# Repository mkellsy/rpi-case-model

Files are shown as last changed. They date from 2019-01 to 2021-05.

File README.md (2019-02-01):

# Raspberry Pi 3 B+ Case with Touchscreen


3D source files for the honeycomb Raspberry Pi case and matching touchscreen case.

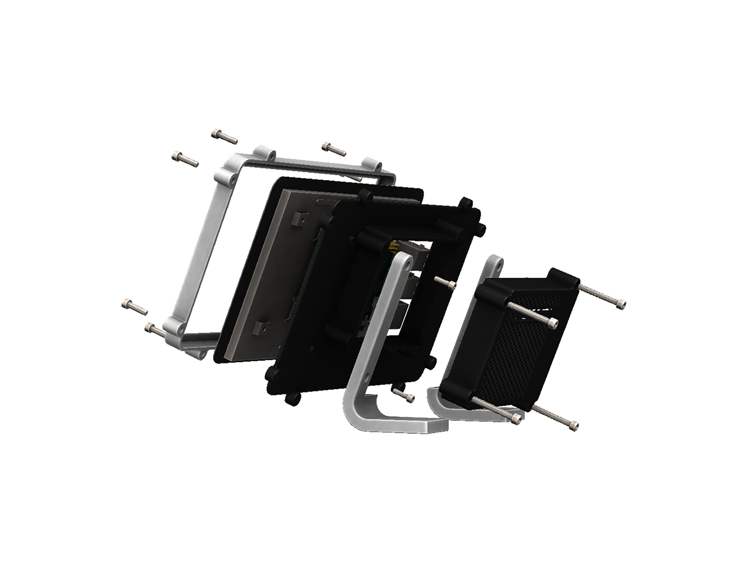
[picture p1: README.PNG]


> This is remixed from 0110-M-P's design on Thingverse, however it is not compatible with it. This has a different bolt pattern.

## Compatibility
- Raspberry Pi 3 Model B+
- Raspberry Pi 3 Model B
- Raspberry Pi 2 Model B
- Raspberry Pi 1 Model B+

## Configurations
This includes multiple mount configurations;
- 75 mm VESA mounts
- 100 mm VESA mounts
- 8020 mounts
- No mounts

Also included are multiple top configurations;
- Standard
- Slotted for display and camera ribbons
- 25 mm and 30 mm fan cutouts
- Clean version (great for modding and remixing)

Special configuration for the official Raspberry Pi touchscreen. Wihch also includes multiple configurations;
- Standard
- Slotted for a camera ribbon
- 25 mm and 30 mm fan cutouts
- Clean version (great for modding and remixing)

## Features
There also is a retainer bracket that can hold the board without using screws inside the case. This bracket does cover the ribbon slots, so it is best used with the default or blank tops. This is not needed fpr the touchscreen because the motherboard attaches to the back of the screen.

## Assembly
To assemble the case you will need;
- 4 x #4-40 x 1/4 socket head cap screws (If you don't use the retainer bracket)
  Used to attach the Raspberry Pi to the base.

- 4 x #6-32 x 3/4 socket head cap screws
  Used to attach the top to the base.

  > The screws will self tap, but it you have a #6-32 tap it is recommended to tab the mount holes on the base.

More detailed instructions can be found here. [Assembly Instructions](https://github.com/mkellsy/rpi-case-model/blob/master/RPI-ASSEMBLY.md).

To assemble the touchscreen case you will need;
- 4 x #4-40 x 3/8 socket head cap screws
  Used to attach the legs and the back to the screen. 

  > The threads on the screen are M3, however #4-40 will work but might alter the threads. I used #4-40 screws because they are easier to find.

- 4 x #6-32 x 1/2 socket head cap screws
  Used to attach the frame to the back.

- 4 x #4-32 x 1 socket head cap screws
  Used to attach the cover to the back.
  
  > The screws will self tap, but it you have a #6-32 tap it is recommended to tab the mount holes on the base.

More detailed instructions can be found here. [Assembly Instructions](https://github.com/mkellsy/rpi-case-model/blob/master/RTS-ASSEMBLY.md).

## Updates

#### 1/21/2019 Update.
- Added slotted, 25 mm fan and 30 mm fan tops without the honeycomb.

#### 1/20/2019 Update.
- Since #4-40 screws are hard to find, I changed the bolt pattern to accommodate #6-32 screws.
- Added support backing for the frame screws.
- Added material behind the frame mounts.
- Added 4 frame mount points to better compress the screen.
- Changed leg geometry to clear the new frame mounts.

#### 1/19/2019 Update.
- Changed the honeycomb pattern, it is much cleaner now.
- Added a retainer that holds the board inside the case without screws.
- Lengthened the touchscreen legs to accommodate larger USB power cables.

#### 1/18/2019 Update.
- Rotated the STL files to lay flat on the print bed. (SolidWorks has a different orientation)
- Added a 8020 mount base.
- Added a slotted top for display and camera ribbons.
- Added a 25 mm and a 30 mm fan top.
- Added a blank top.
- Added a slotted back cover for a camera ribbon.
- Added a 25 mm and a 30 mm fan back cover.
- Added a blank back cover.

#### 1/17/2019 Update.
- Added a no mount base.
- Added a 100 mm VESA mount base.
- Combined the left and right legs into one STL file.
- Increased the thickness of the legs to better fit #4-40 x 3/8 screws without contacting the back of the screen.

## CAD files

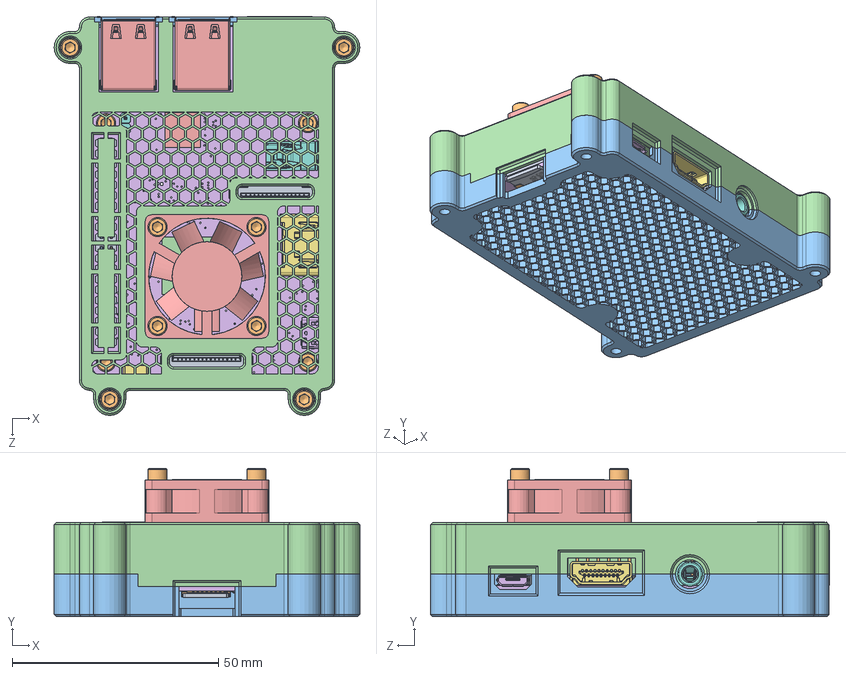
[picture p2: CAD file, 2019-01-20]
RPI-CASE.SLDASM
74.2 x 36.0 x 96.8 mm
Raspberry Pi 3157
Raspberry Pi 3242 x 20
Raspberry Pi 3266 x 20
raspberry_pi_3(bar_180_2x20)
MOLEX_672983090 x 2
molex_0473460001
molex_0471510001
PJ-322
te_1-1734248-5 x 2
MOLEX_1040310811
raspberry_pi_B_(RJ45)
Raspberry Pi 312
Raspberry Pi 314
Raspberry Pi 31
Raspberry Pi 36
Strait Headers
raspberry_pi_B+_(microsd2)
socket head cap screw_ai x 12
RPI-BOTTOM
RPI-TOP-30FAN
30MM-FAN

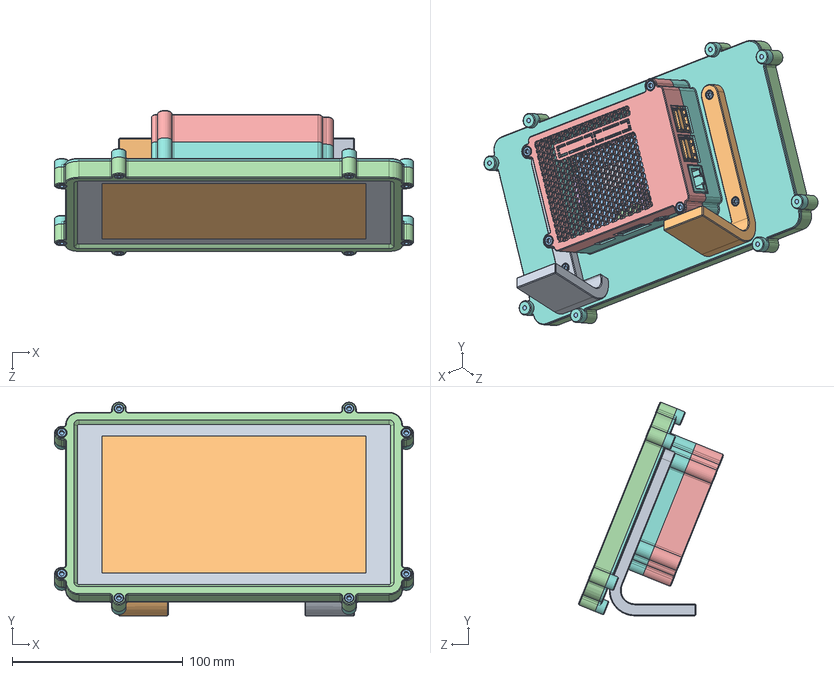
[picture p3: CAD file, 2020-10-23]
RPI3B/TOUCHSCREEN-CASE.SLDASM
210.5 x 125.3 x 85.0 mm
FRAME
FRONT-GLASS
HOUSING
DRIVER-BOARD
RAISER x 4
Raspberry Pi 3157
Raspberry Pi 3242 x 20
Raspberry Pi 3266 x 20
raspberry_pi_3(bar_180_2x20)
MOLEX_672983090 x 2
molex_0473460001
molex_0471510001
PJ-322
te_1-1734248-5 x 2
MOLEX_1040310811
raspberry_pi_B_(RJ45)
Raspberry Pi 312
Raspberry Pi 314
Raspberry Pi 31
Raspberry Pi 36
Strait Headers
raspberry_pi_B+_(microsd2)
pan cross head_am x 4
RTS-BACK
RTS-LEFT-LEG
RTS-RIGHT-LEG
socket head cap screw_ai x 16
RTS-FRAME
RTS-COVER

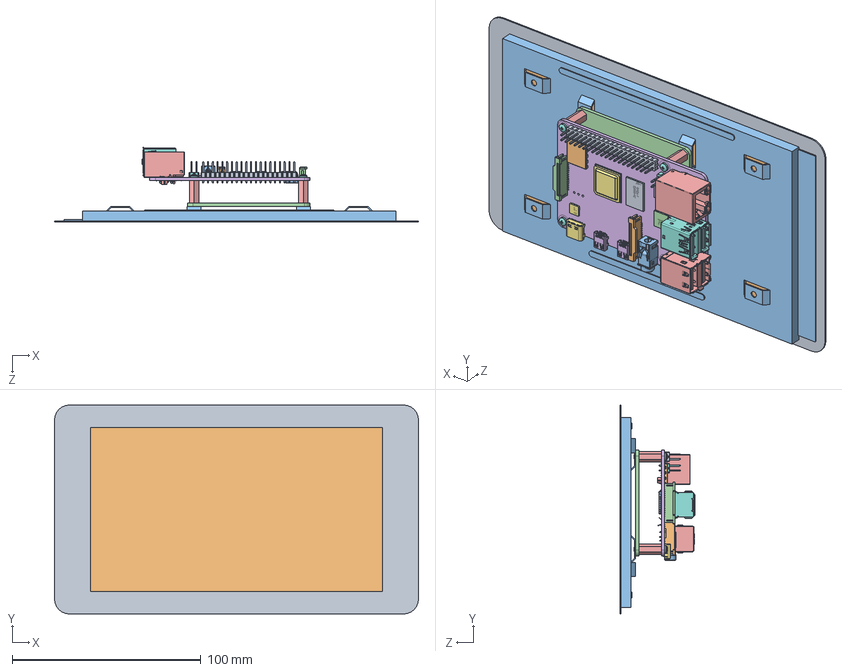
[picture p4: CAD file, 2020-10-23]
RPI4B/TOUCHSCREEN.SLDASM
193.0 x 110.8 x 40.0 mm
FRAME
FRONT-GLASS
HOUSING
DRIVER-BOARD
RAISER x 4
PCB, RPi4ModelB
Broadcom BCM2711B0 CPU, RPi4ModelB
2.54 mm DUPONT MALE PIN HEADER, POE, 2X2, RPi4ModelB
2.54 mm DUPONT MALE PIN HEADER, IO, 2X20, RPi4ModelB
Camera Connector, RPi4ModelB
Microphone Plug, RPi4ModelB
Display Connector, RPi4ModelB
Gigabit Ethernet Port, RPi4ModelB
Female Micro HDMI Connector, RPi4ModelB x 2
Female USB Type C Connector, RPi4ModelB
2X USB3.0 PORTS, RPi4ModelB
91D77 D9WHV 778K, 4 GB LPDDR4 SDRAM, RPi4ModelB
Cypress CYW43455 Wireless Module Cover, RPi4ModelB
SD Card Slot, RPi4ModelB
VIA VL805 PCIe USB 3.0 controller, RPi4ModelB
2X USB2.0 PORTS, RPi4ModelB
Broadcom BCM54213PE Gigabit Ethernet Transceiver, RPi4ModelB
MxL7704 Universal PMIC, RPi4ModelB
pan cross head_am x 4

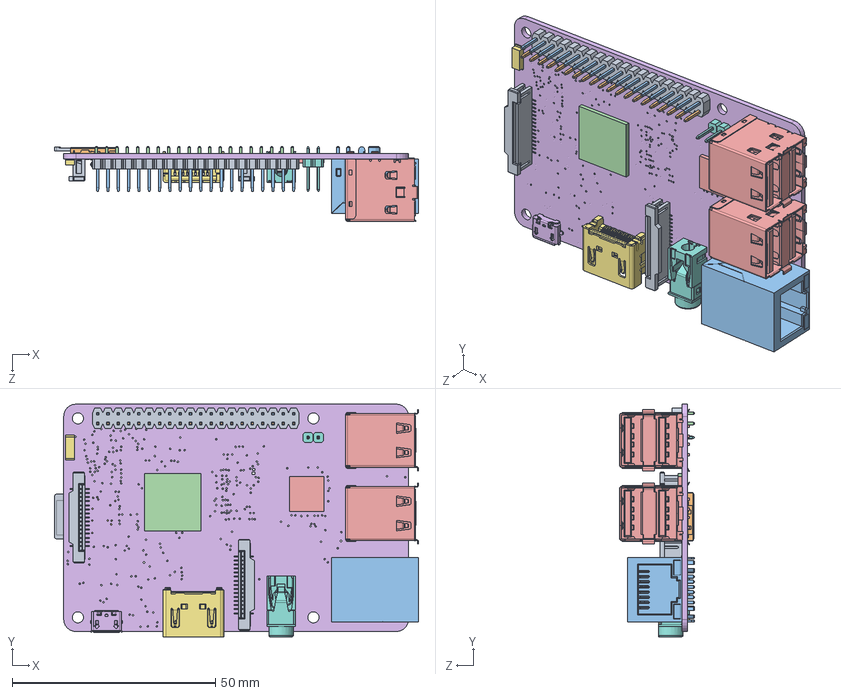
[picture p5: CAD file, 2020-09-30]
RPI3B/BOARD.SLDASM
89.6 x 57.3 x 18.6 mm
Raspberry Pi 3157
Raspberry Pi 3242 x 20
Raspberry Pi 3266 x 20
raspberry_pi_3(bar_180_2x20)
MOLEX_672983090 x 2
molex_0473460001
molex_0471510001
PJ-322
te_1-1734248-5 x 2
MOLEX_1040310811
raspberry_pi_B_(RJ45)
Raspberry Pi 312
Raspberry Pi 314
Raspberry Pi 31
Raspberry Pi 36
Strait Headers
raspberry_pi_B+_(microsd2)

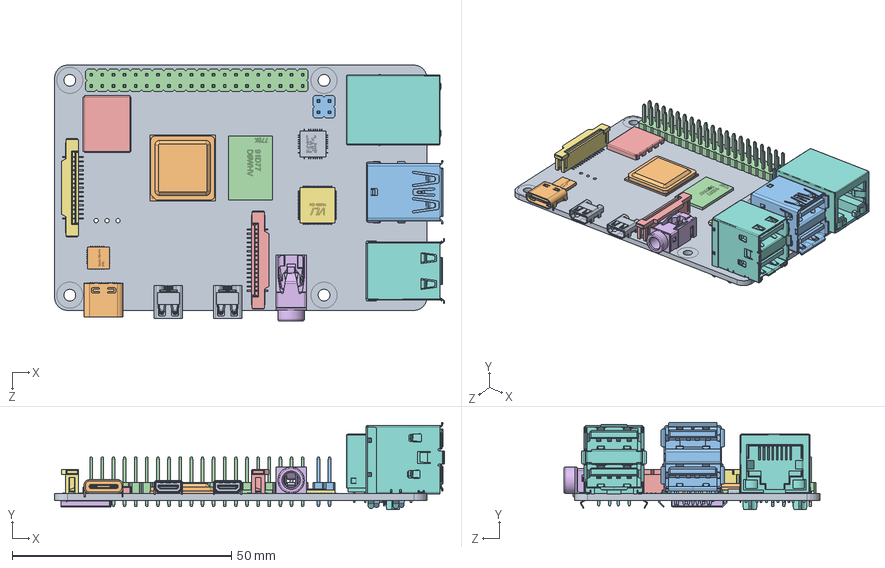
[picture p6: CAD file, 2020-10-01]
RPI4B/BOARD.SLDASM
89.0 x 19.9 x 58.4 mm
PCB, RPi4ModelB
Broadcom BCM2711B0 CPU, RPi4ModelB
2.54 mm DUPONT MALE PIN HEADER, POE, 2X2, RPi4ModelB
2.54 mm DUPONT MALE PIN HEADER, IO, 2X20, RPi4ModelB
Camera Connector, RPi4ModelB
Microphone Plug, RPi4ModelB
Display Connector, RPi4ModelB
Gigabit Ethernet Port, RPi4ModelB
Female Micro HDMI Connector, RPi4ModelB x 2
Female USB Type C Connector, RPi4ModelB
2X USB3.0 PORTS, RPi4ModelB
91D77 D9WHV 778K, 4 GB LPDDR4 SDRAM, RPi4ModelB
Cypress CYW43455 Wireless Module Cover, RPi4ModelB
SD Card Slot, RPi4ModelB
VIA VL805 PCIe USB 3.0 controller, RPi4ModelB
2X USB2.0 PORTS, RPi4ModelB
Broadcom BCM54213PE Gigabit Ethernet Transceiver, RPi4ModelB
MxL7704 Universal PMIC, RPi4ModelB

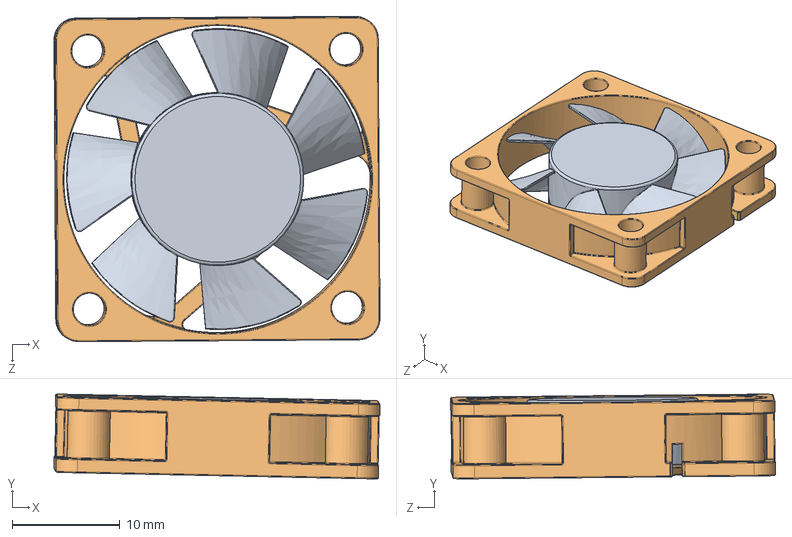
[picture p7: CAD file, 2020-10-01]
RPI4B/COMPONENTS/FAN.SLDASM
30.3 x 7.87 x 30.2 mm
BLADES
HOUSING

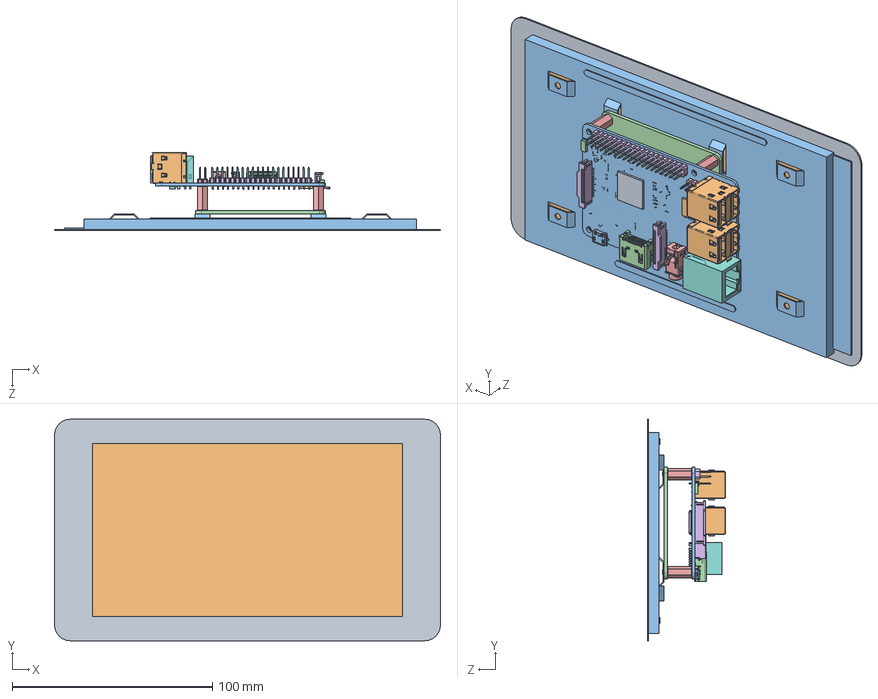
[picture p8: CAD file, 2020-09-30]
RPI3B/TOUCHSCREEN.SLDASM
193.0 x 110.8 x 39.2 mm
FRAME
FRONT-GLASS
HOUSING
DRIVER-BOARD
RAISER x 4
Raspberry Pi 3157
Raspberry Pi 3242 x 20
Raspberry Pi 3266 x 20
raspberry_pi_3(bar_180_2x20)
MOLEX_672983090 x 2
molex_0473460001
molex_0471510001
PJ-322
te_1-1734248-5 x 2
MOLEX_1040310811
raspberry_pi_B_(RJ45)
Raspberry Pi 312
Raspberry Pi 314
Raspberry Pi 31
Raspberry Pi 36
Strait Headers
raspberry_pi_B+_(microsd2)

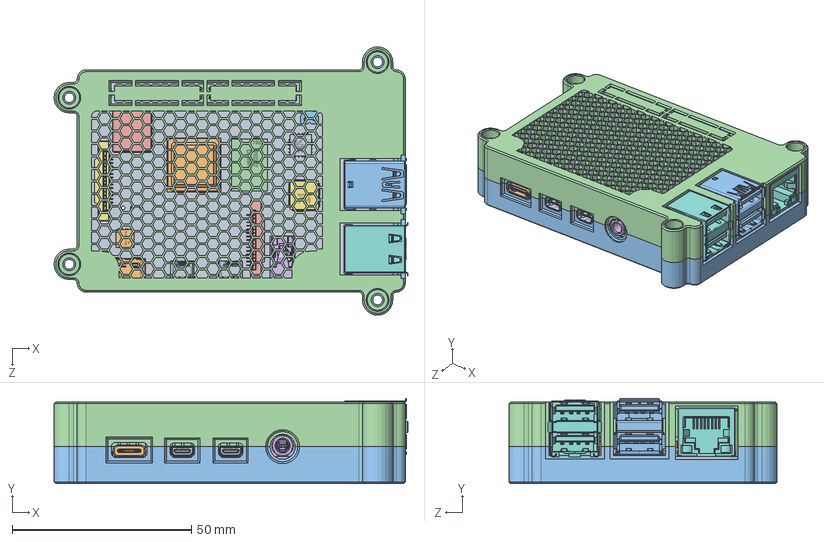
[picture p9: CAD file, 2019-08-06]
RPI4B/CASE.SLDASM
98.8 x 23.8 x 74.9 mm
PCB, RPi4ModelB
Broadcom BCM2711B0 CPU, RPi4ModelB
2.54 mm DUPONT MALE PIN HEADER, POE, 2X2, RPi4ModelB
2.54 mm DUPONT MALE PIN HEADER, IO, 2X20, RPi4ModelB
Camera Connector, RPi4ModelB
Microphone Plug, RPi4ModelB
Display Connector, RPi4ModelB
Gigabit Ethernet Port, RPi4ModelB
Female Micro HDMI Connector, RPi4ModelB x 2
Female USB Type C Connector, RPi4ModelB
2X USB3.0 PORTS, RPi4ModelB
91D77 D9WHV 778K, 4 GB LPDDR4 SDRAM, RPi4ModelB
Cypress CYW43455 Wireless Module Cover, RPi4ModelB
SD Card Slot, RPi4ModelB
VIA VL805 PCIe USB 3.0 controller, RPi4ModelB
2X USB2.0 PORTS, RPi4ModelB
Broadcom BCM54213PE Gigabit Ethernet Transceiver, RPi4ModelB
MxL7704 Universal PMIC, RPi4ModelB
BOTTOM
TOP

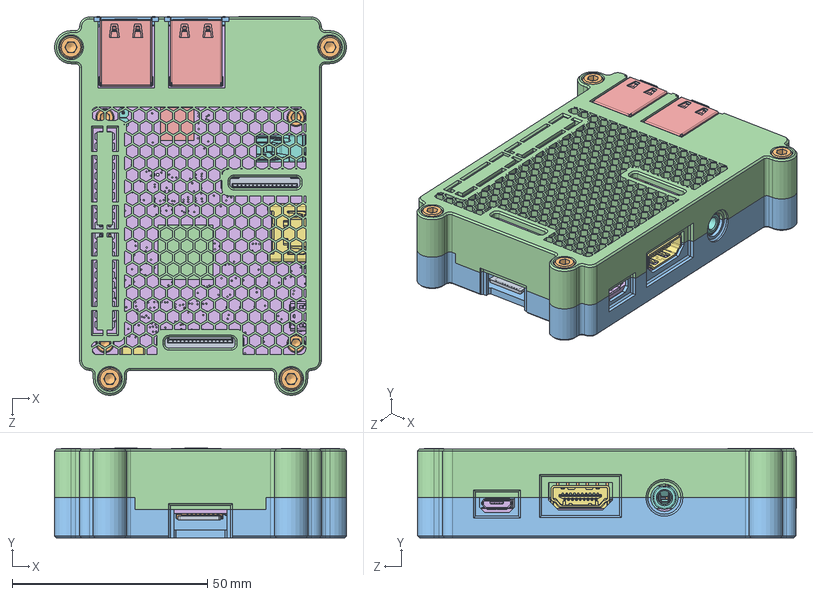
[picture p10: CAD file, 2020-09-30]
RPI3B/CASE.SLDASM
74.9 x 23.0 x 97.2 mm
Raspberry Pi 3157
Raspberry Pi 3242 x 20
Raspberry Pi 3266 x 20
raspberry_pi_3(bar_180_2x20)
MOLEX_672983090 x 2
molex_0473460001
molex_0471510001
PJ-322
te_1-1734248-5 x 2
MOLEX_1040310811
raspberry_pi_B_(RJ45)
Raspberry Pi 312
Raspberry Pi 314
Raspberry Pi 31
Raspberry Pi 36
Strait Headers
raspberry_pi_B+_(microsd2)
socket head cap screw_ai x 8
RPI-BOTTOM
RPI-TOP-SLOTTED

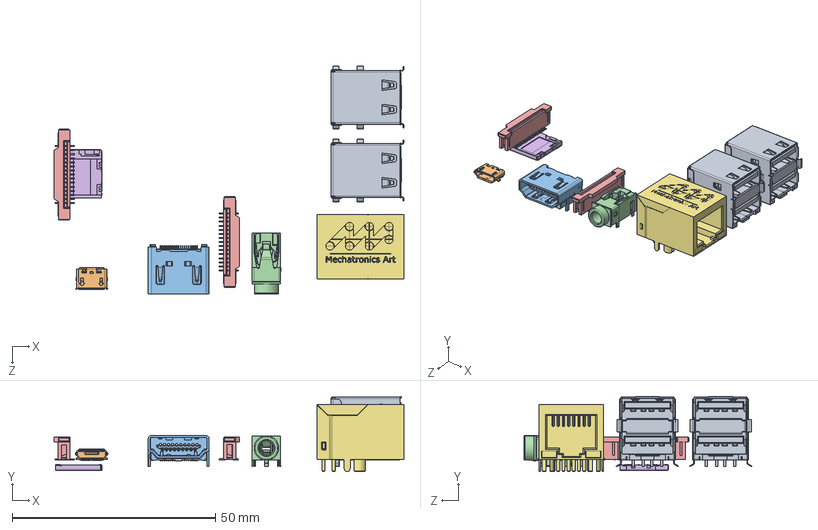
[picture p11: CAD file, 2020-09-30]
RPI3B/BOARD/RPi3_ModelB v1.sldasm
86.1 x 18.5 x 56.1 mm
MOLEX_672983090 x 2
molex_0473460001
molex_0471510001
PJ-322
te_1-1734248-5 x 2
MOLEX_1040310811
raspberry_pi_B_(RJ45)

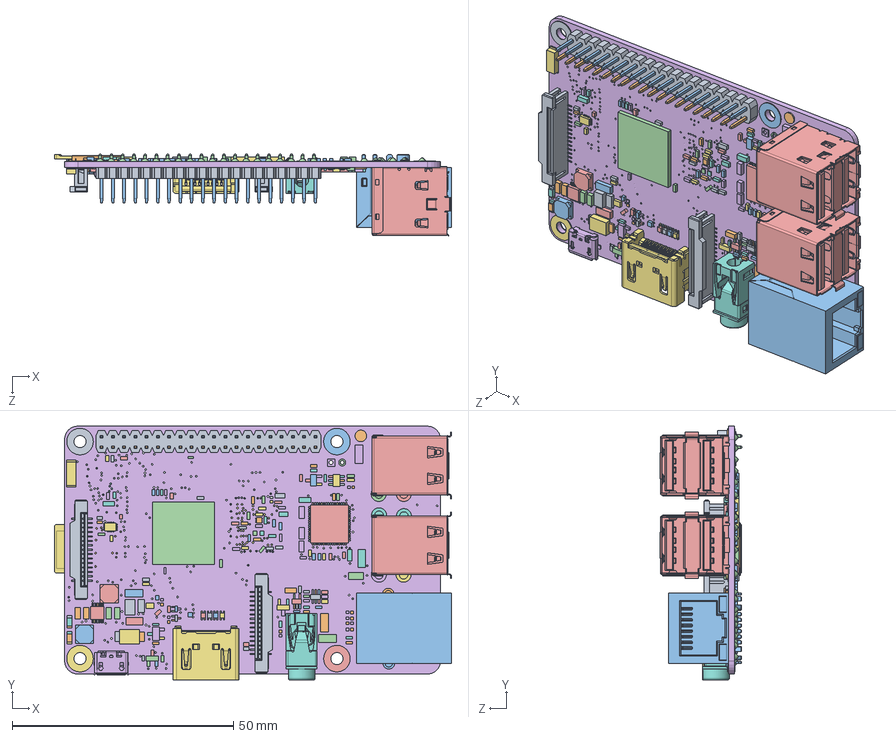
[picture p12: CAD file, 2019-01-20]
RPI3B/BOARD/RPI.SLDASM
89.6 x 57.3 x 18.6 mm
Raspberry Pi 3157
Raspberry Pi 3242 x 20
Raspberry Pi 3266 x 20
raspberry_pi_3(bar_180_2x20)
MOLEX_672983090 x 2
molex_0473460001
molex_0471510001
PJ-322
te_1-1734248-5 x 2
MOLEX_1040310811
raspberry_pi_B_(RJ45)
Raspberry Pi 312
Raspberry Pi 314
Raspberry Pi 3172
Raspberry Pi 3173
Raspberry Pi 3174
Raspberry Pi 3175
Raspberry Pi 3176
Raspberry Pi 3177
Raspberry Pi 3178
Raspberry Pi 3179
Raspberry Pi 3180
Raspberry Pi 3181
Raspberry Pi 3182
Raspberry Pi 3183
Raspberry Pi 3184
Raspberry Pi 3185
Raspberry Pi 3186
Raspberry Pi 3187
Raspberry Pi 3188
Raspberry Pi 3189
Raspberry Pi 3190
Raspberry Pi 3191
Raspberry Pi 3192
Raspberry Pi 3193
Raspberry Pi 3194
Raspberry Pi 3195
Raspberry Pi 3196
Raspberry Pi 3197
Raspberry Pi 3198
Raspberry Pi 3199
Raspberry Pi 3200
Raspberry Pi 3201
Raspberry Pi 3202
Raspberry Pi 3203
Raspberry Pi 3204
Raspberry Pi 3205
Raspberry Pi 3206
Raspberry Pi 3207
Raspberry Pi 3208
Raspberry Pi 3209
Raspberry Pi 3210
Raspberry Pi 3211
Raspberry Pi 3212
Raspberry Pi 3213
Raspberry Pi 3214
Raspberry Pi 3215
Raspberry Pi 3216
Raspberry Pi 3217
Raspberry Pi 3218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

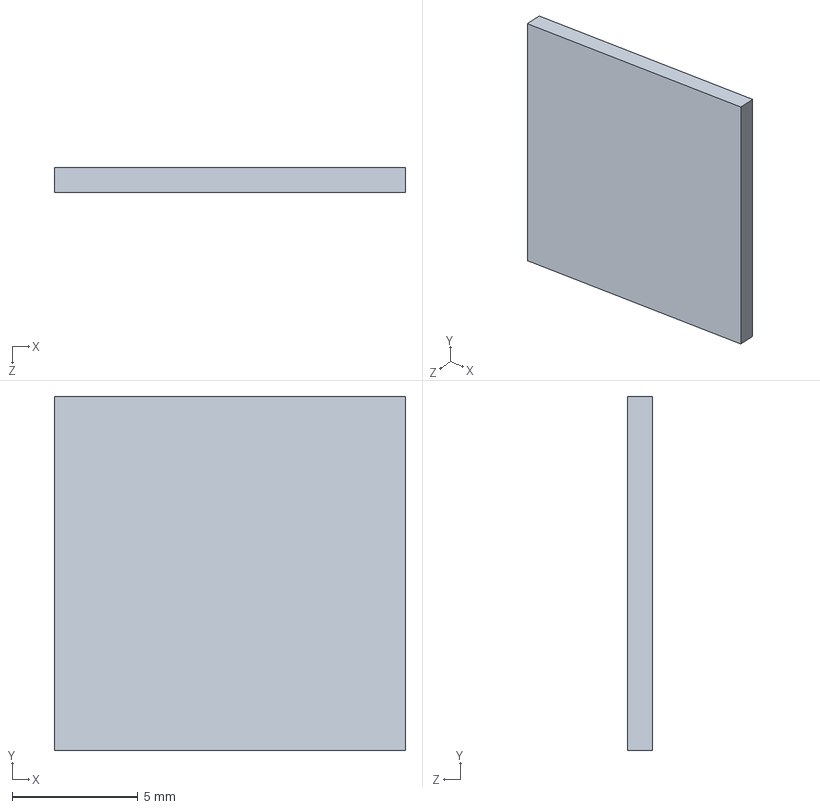
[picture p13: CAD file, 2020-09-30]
RPI3B/BOARD/Raspberry Pi 312.sldprt
14.0 x 14.1 x 1.00 mm

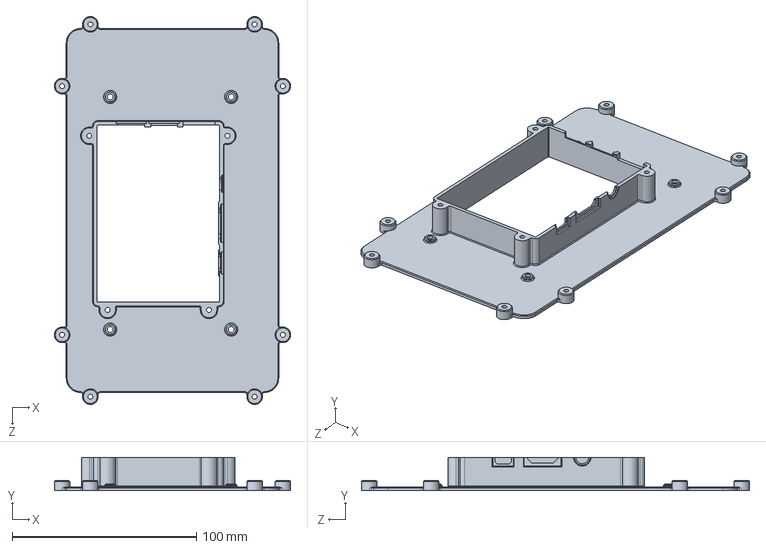
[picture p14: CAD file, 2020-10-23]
RPI3B/CASE/RTS-BACK.SLDPRT
128.3 x 18.1 x 210.5 mm

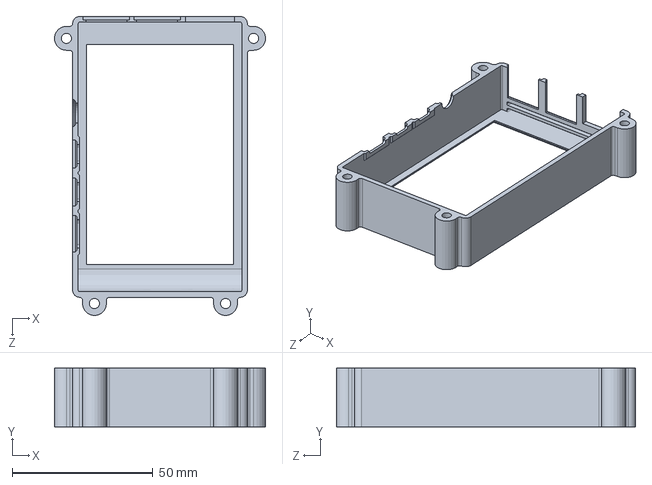
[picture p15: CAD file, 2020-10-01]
RPI4B/BLOWER/TOUCHSCREEN.SLDPRT
74.9 x 20.8 x 106.1 mm

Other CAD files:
RPI3B/PUBLISH/RTS-BACK.STL
RPI4B/BOARD/Gigabit Ethernet Port, RPi4ModelB.SLDPRT
RPI4B/CASE/BEZEL.SLDPRT
RPI4B/COMPONENTS/HOUSING.SLDPRT
RPI3B/BOARD/25MM-FAN.SLDPRT
RPI3B/BOARD/25MM-FAN.STEP
RPI3B/BOARD/30MM-FAN.SLDPRT
RPI3B/BOARD/30MM-FAN.STEP
RPI3B/BOARD/HANRUN2_HR911105A.sldprt
RPI3B/BOARD/MOLEX_1040310811.sldprt
RPI3B/BOARD/MOLEX_672983090.sldprt
RPI3B/BOARD/PJ-322.sldprt
RPI3B/BOARD/Raspberry Pi 31.sldprt
RPI3B/BOARD/Raspberry Pi 310.sldprt
RPI3B/BOARD/Raspberry Pi 3100.sldprt
RPI3B/BOARD/Raspberry Pi 3101.sldprt
RPI3B/BOARD/Raspberry Pi 3102.sldprt
RPI3B/BOARD/Raspberry Pi 3103.sldprt
RPI3B/BOARD/Raspberry Pi 3104.sldprt
RPI3B/BOARD/Raspberry Pi 3105.sldprt
RPI3B/BOARD/Raspberry Pi 3106.sldprt
RPI3B/BOARD/Raspberry Pi 3107.sldprt
RPI3B/BOARD/Raspberry Pi 3108.sldprt
RPI3B/BOARD/Raspberry Pi 3109.sldprt
RPI3B/BOARD/Raspberry Pi 311.sldprt
RPI3B/BOARD/Raspberry Pi 3110.sldprt
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

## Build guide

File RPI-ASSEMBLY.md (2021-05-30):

# Raspberry Pi Case Assembly Instructions
This guide will walk you through assembling the Raspberry Pi case. All of the tools and hardware should be available at Amazon, Home Depot or Ace Hardware.

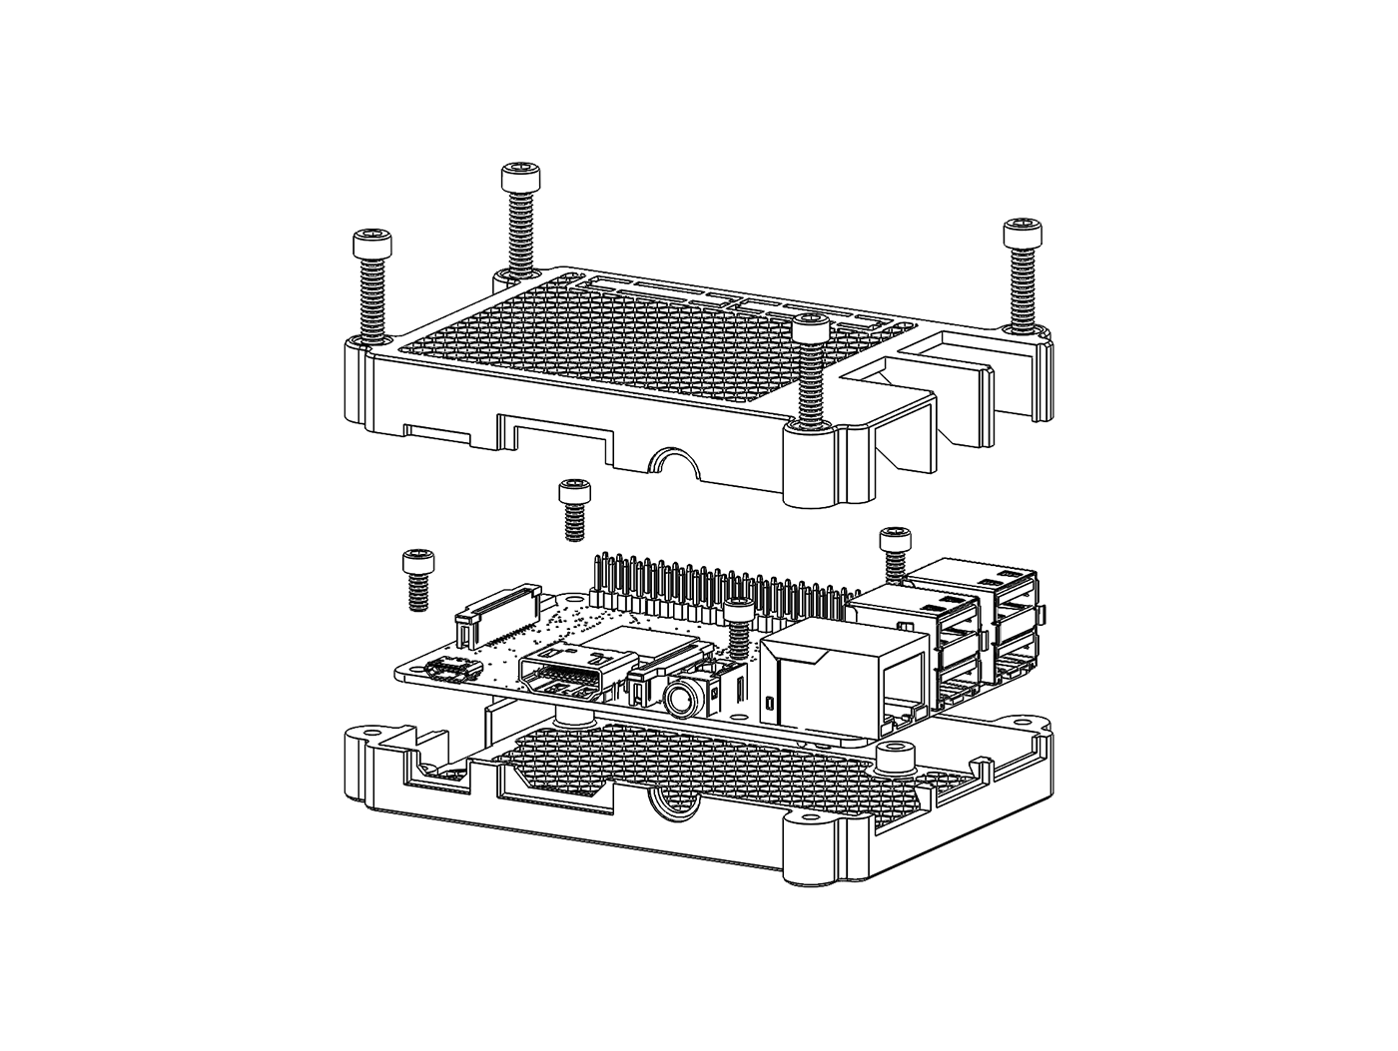
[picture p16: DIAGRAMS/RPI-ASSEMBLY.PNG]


## Required Tools and Hardware
- A #6-32 tap.
- 7/64 and 3/32 hex wrench.
- 4 x #4-40 x 1/4 stainless socket head cap screws. (RPI 3 Version Only)
- 4 x #6-32 x 3/4 stainless socket head cap screws.

> M3 screws will work too. Imperial threads are listed because they are easier to find in the U.S.

## Tapping
First you will need to tap the holes on the RPI-BOTTOM. Tapping is not required as the screws are harder than the plastic. However tapping will create a more consistant thread, as tapping removes material vs. compressing it.

## Assembly
Once you are finished printing the parts, you are now ready to assemble.

### Step 1
Attach the Raspberry Pi to the RPI-BOTTOM.

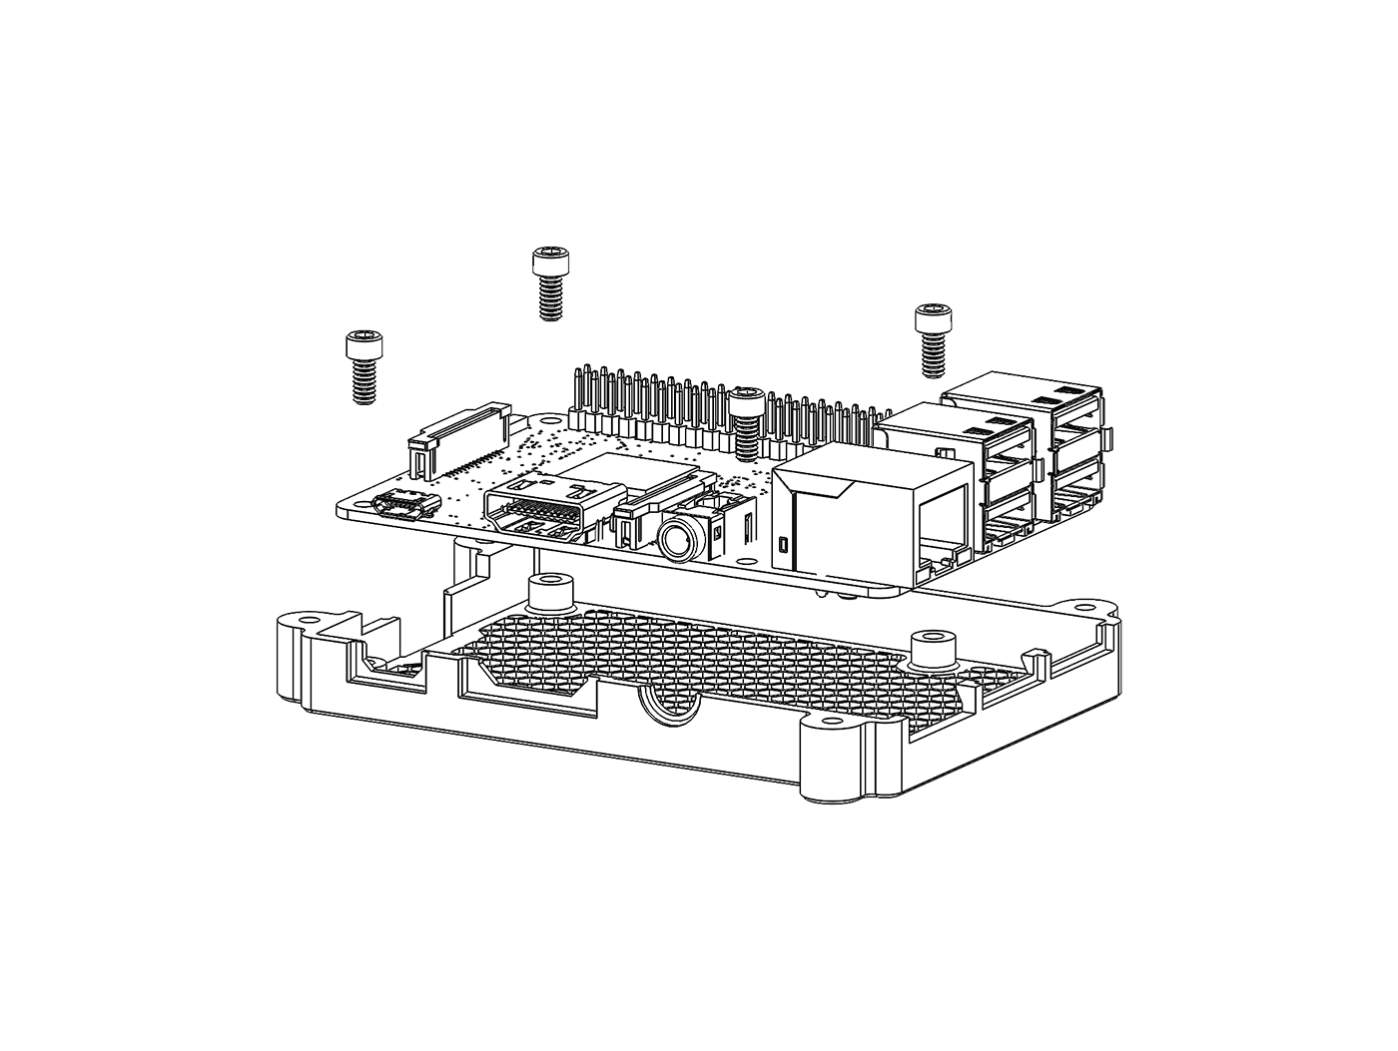
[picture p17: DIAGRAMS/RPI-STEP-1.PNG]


1. Allign the board to the 4 raisers on the RPI-BOTTOM.
2. Attach using 4 #4-40 x 1/4 stainless socket head cap screws. (RPI 3 Version Only)

  > #4-40 taps are hard to find. These screws will need to be self tapped.

### Step 2
Attach the RPI-TOP.

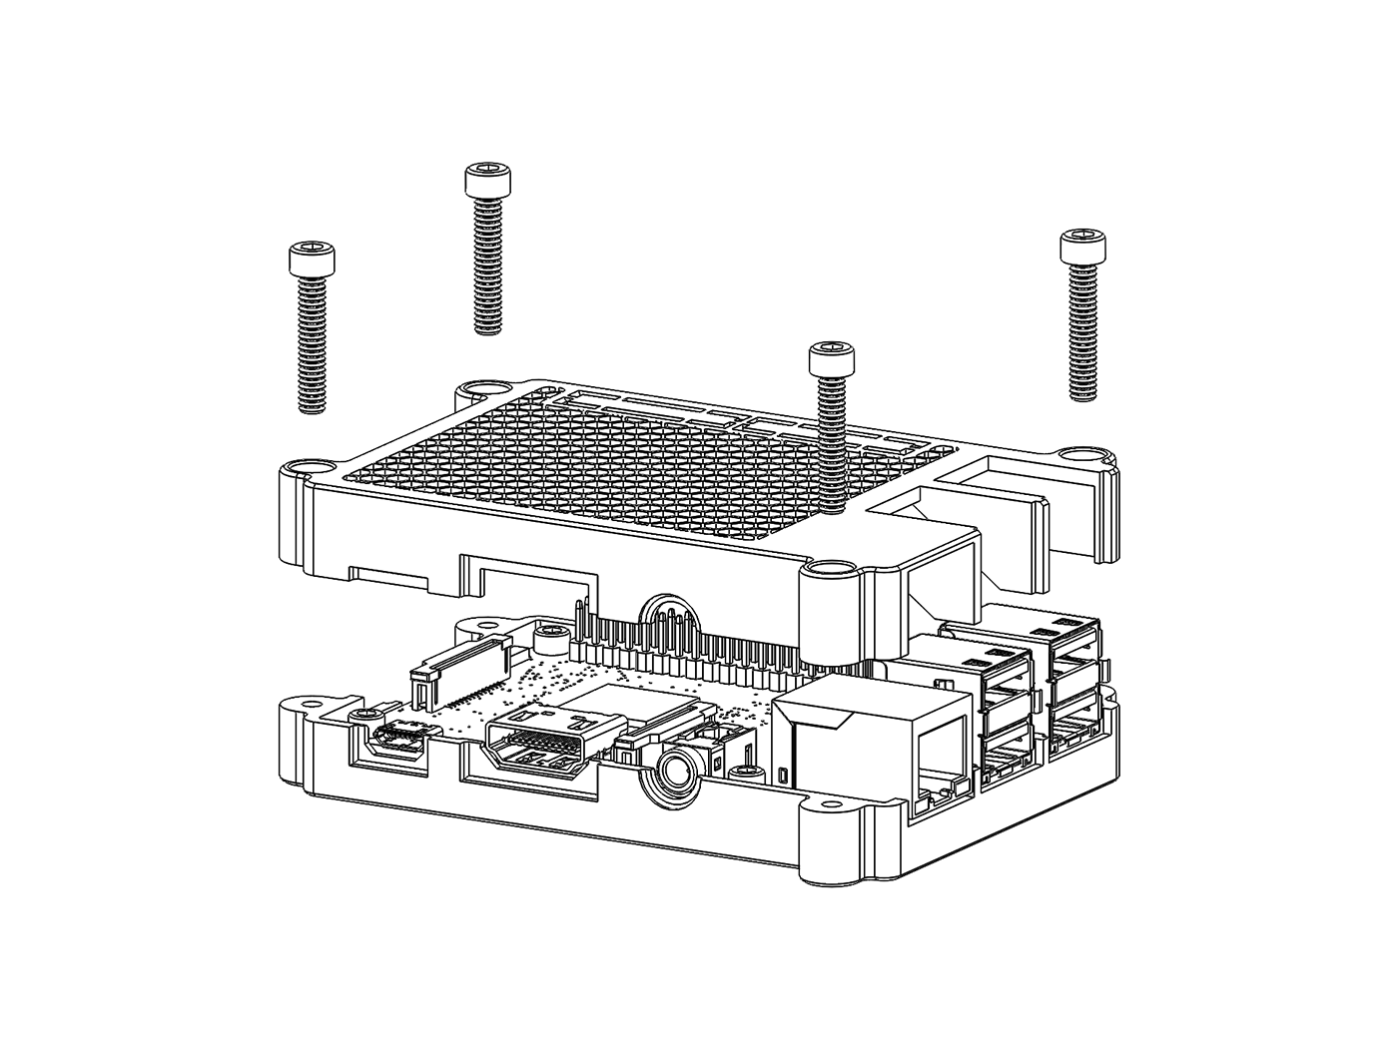
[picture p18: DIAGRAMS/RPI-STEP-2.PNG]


1. Allign the top with the four mount points on the RPI-BOTTOM.
2. Secure the RPI-TOP with 4 #6-32 x 3/4 stainless socket head cap screws.

## Assembly, Screwless Version (RPI 3 Version Only)
If you do not want to secure the Raspberry Pi into the case using screws, you can use the retainer and not use the screws.

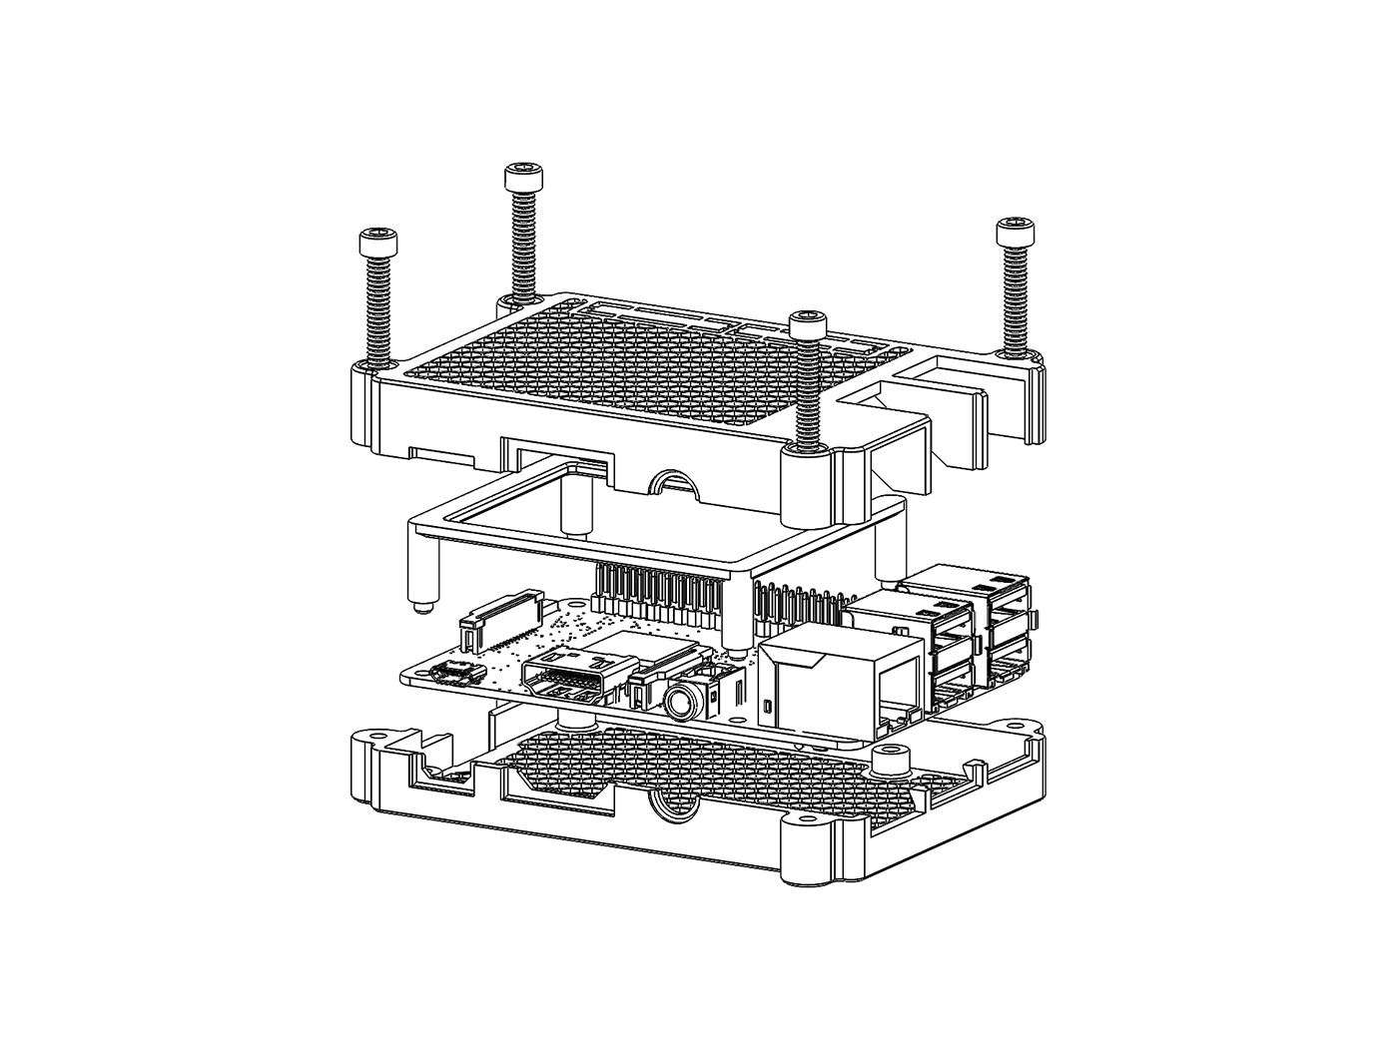
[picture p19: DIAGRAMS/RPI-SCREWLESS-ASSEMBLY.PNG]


> The RPI 4 version has the retainer built into the top.

### Step 1
Position the Raspberry Pi and the RPI-RETAINER in the RPI-BOTTOM.

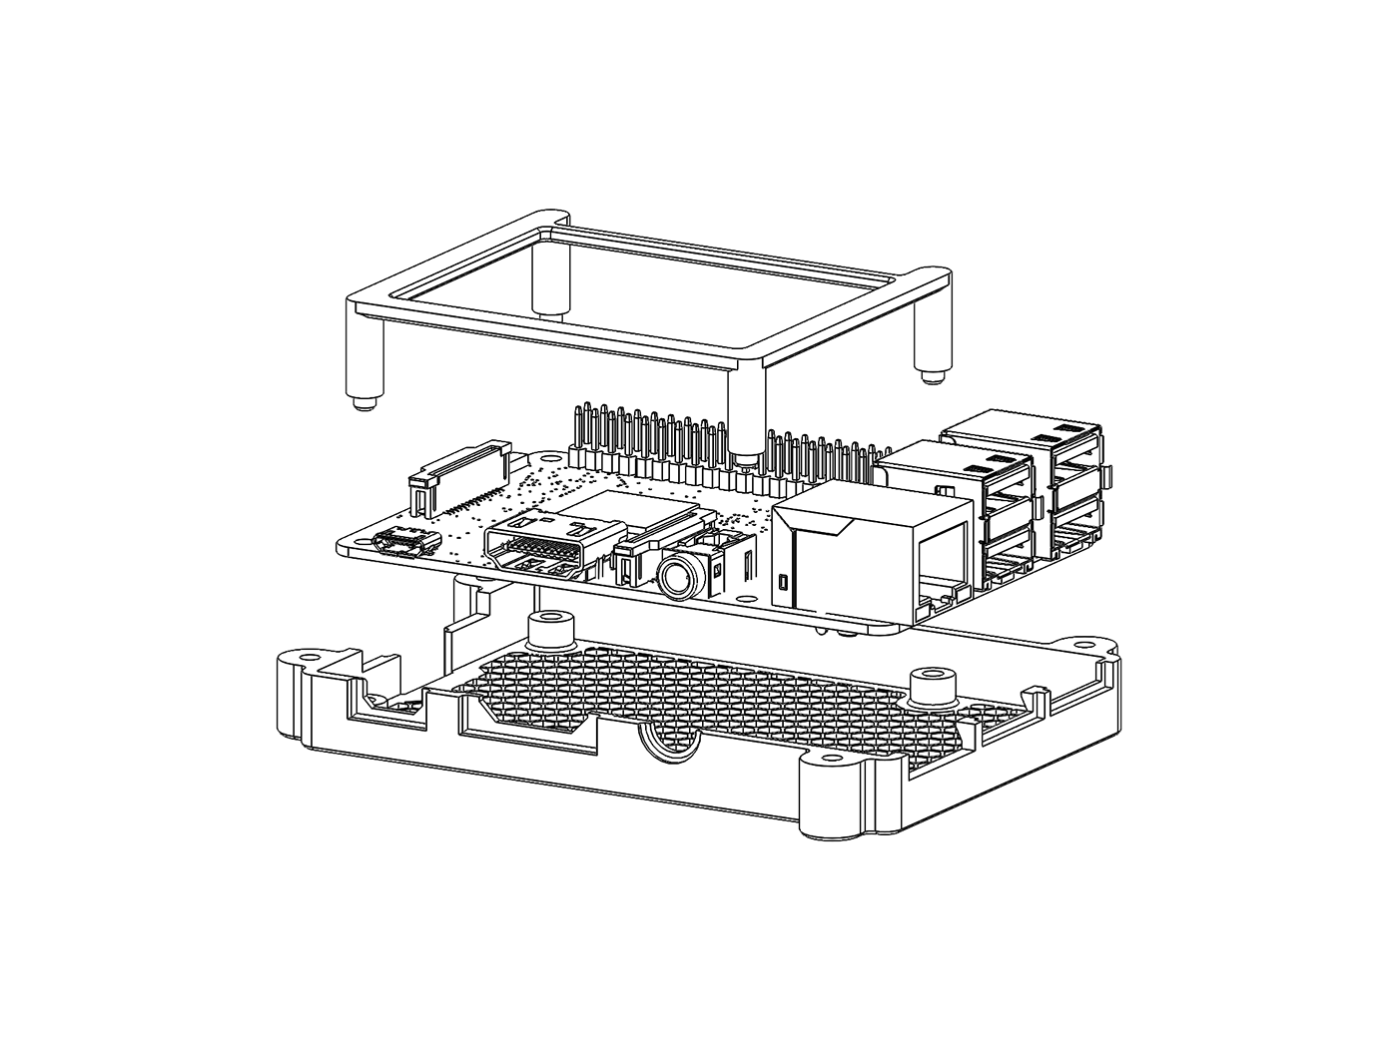
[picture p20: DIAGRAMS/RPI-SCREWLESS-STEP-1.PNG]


1. Allign the board to the 4 raisers on the RPI-BOTTOM.
2. Place the RPI-RETAINER into the 4 raisers on the RPI-BOTTOM through the board.

  > One side of the retainer is offset. This is done to clear the pins on the Raspberry Pi.

### Step 2
Attach the RPI-TOP.

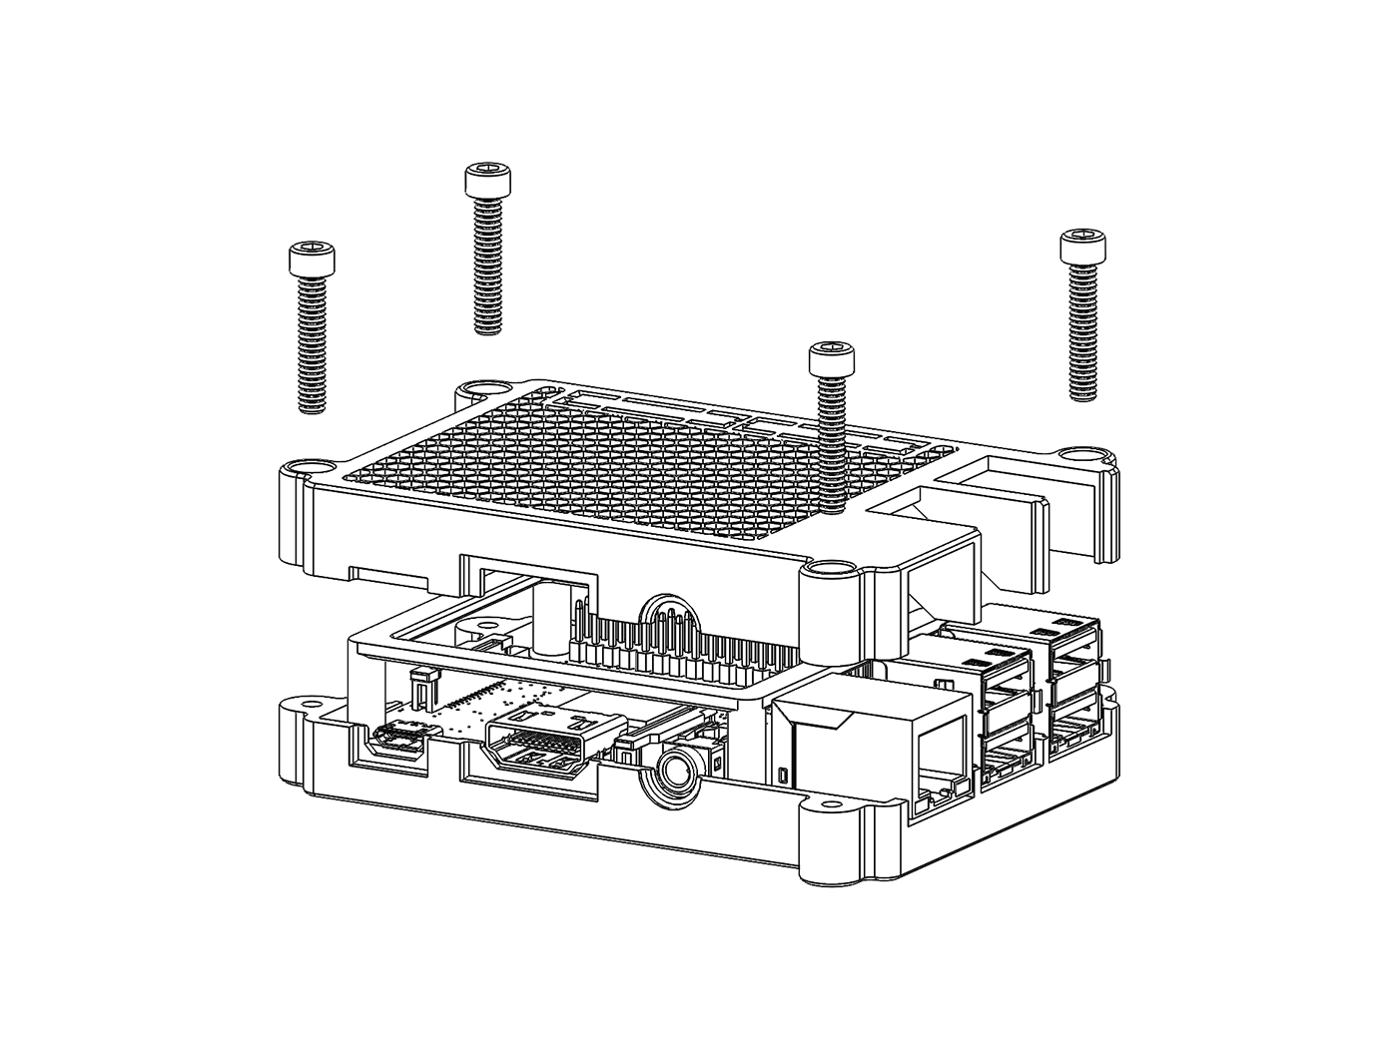
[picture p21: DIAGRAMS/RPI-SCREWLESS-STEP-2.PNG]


1. Allign the top with the four mount points on the RPI-BOTTOM.
2. Secure the RPI-TOP with 4 #6-32 x 3/4 stainless socket head cap screws.

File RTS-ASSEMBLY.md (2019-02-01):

# Touchscreen Case Assembly Instructions
This guide will walk you through assembling the touchscreen case. All of the tools and hardware should be available at Amazon, Home Depot or Ace Hardware.

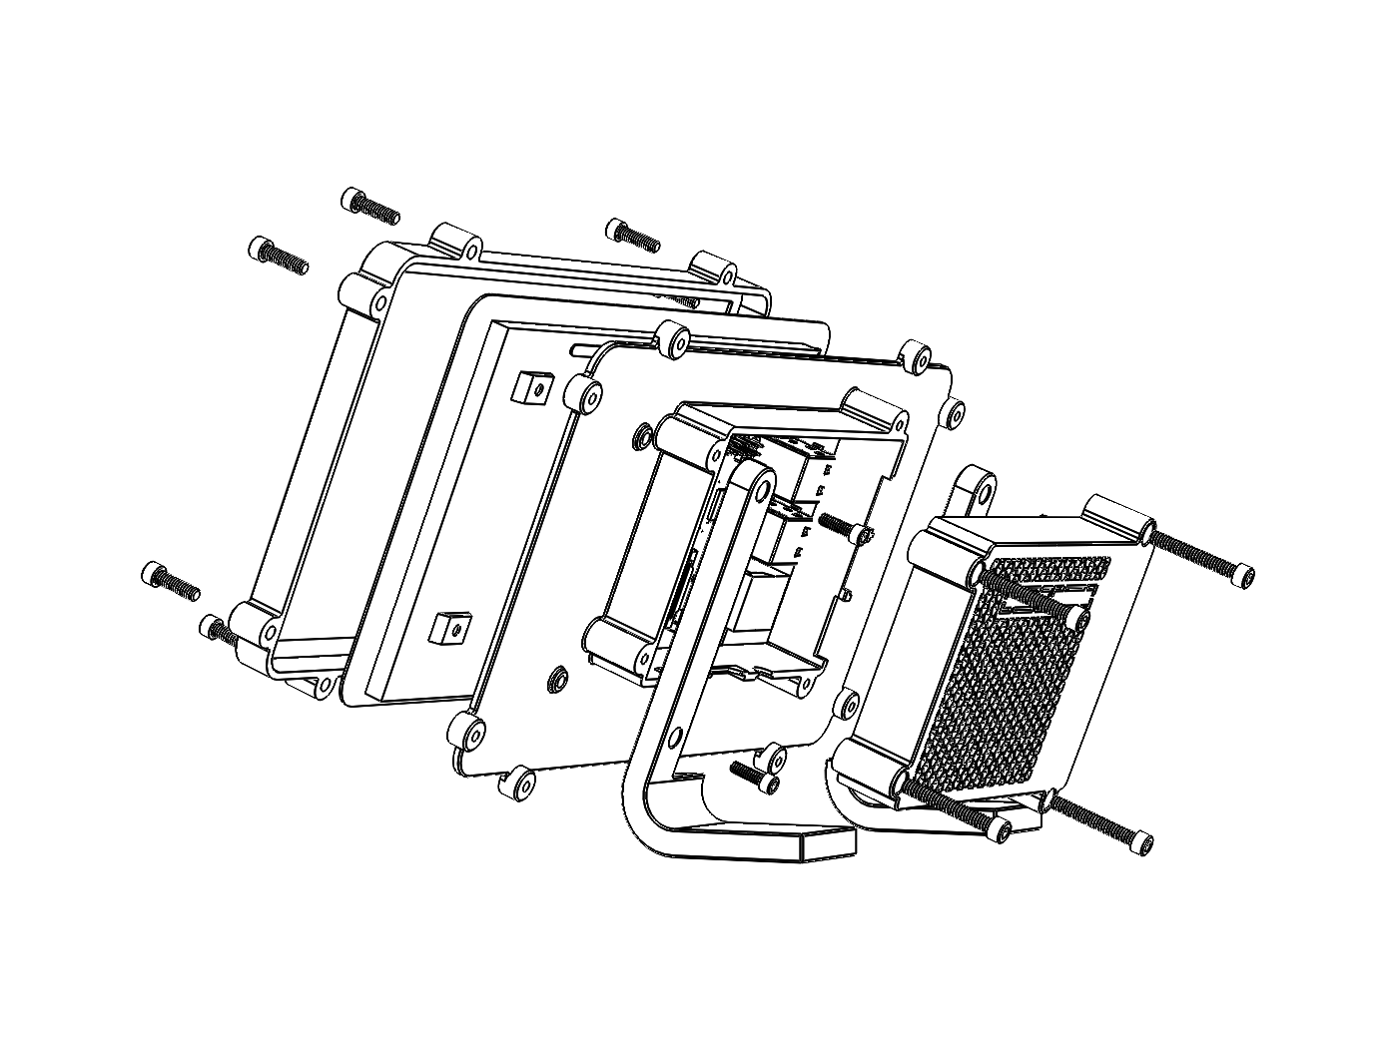
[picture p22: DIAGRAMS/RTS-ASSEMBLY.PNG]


## Required Tools and Hardware
- A #6-32 tap.
- 7/64 and 3/32 hex wrench.
- 4 x #4-40 x 3/8 stainless socket head cap screws.
- 8 x #6-32 x 1/2 stainless socket head cap screws.
- 4 x #6-32 x 1 stainless socket head cap screws.

## Tapping
First you will need to tap the holes on the RTS-BACK. The four holes that attach the RTS-COVER to the RTS-BACK, and the 8 holes that attach the RTS-FRAME to the RTS Back, will need to be tapped.

## Assembly
Once you are finished printing the parts, you are now ready to assemble.

### Step 1
Assemble the Raspberry Pi touchscreen.

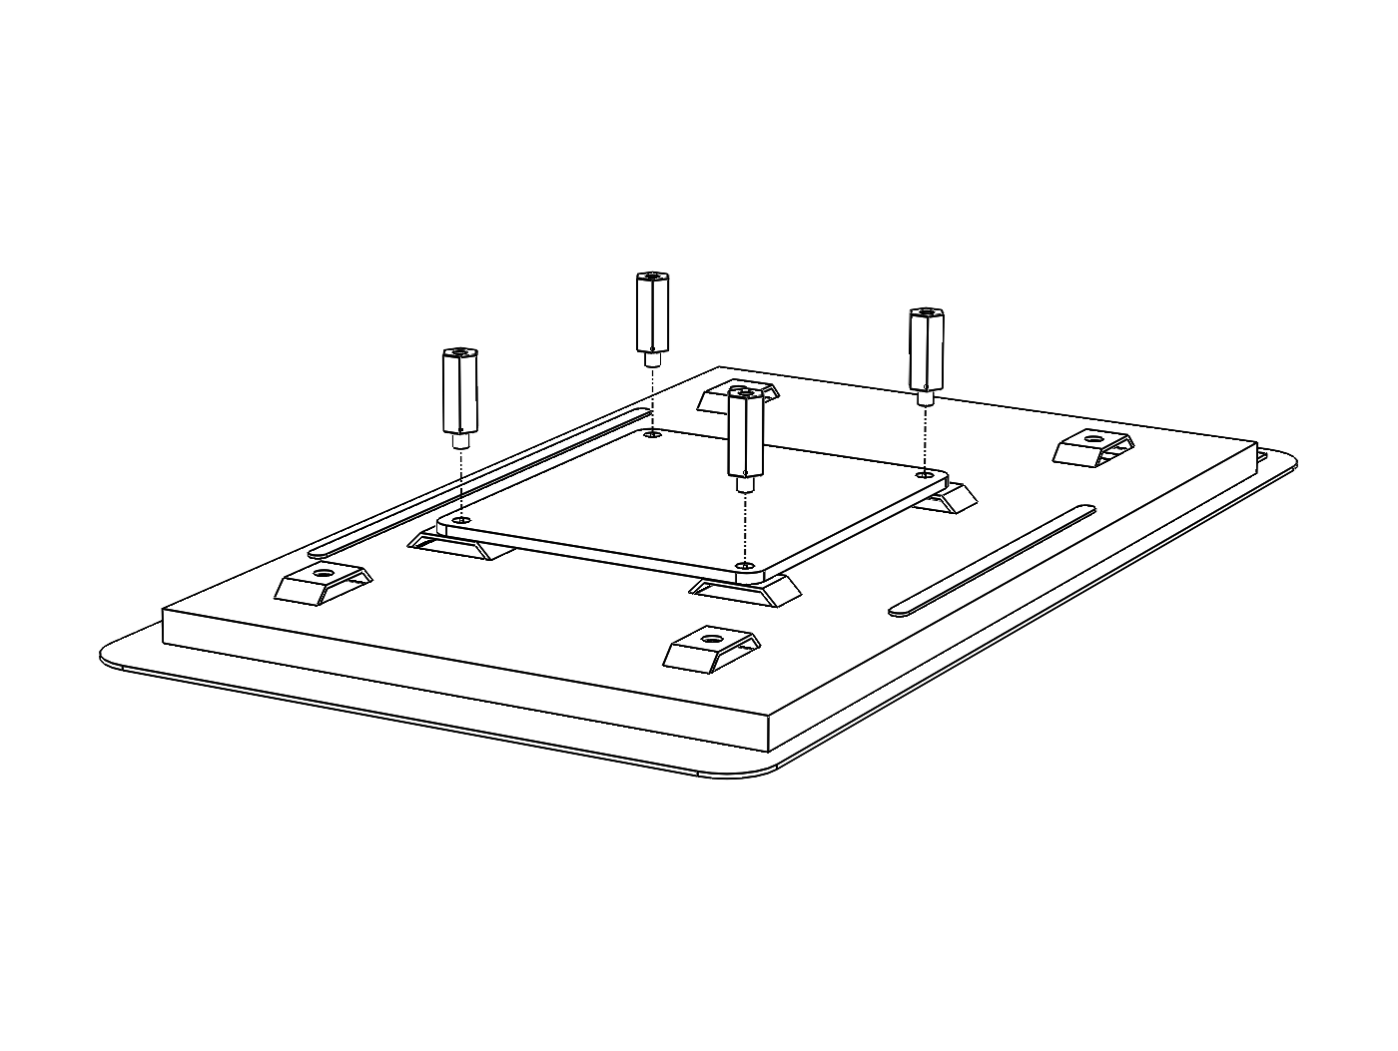
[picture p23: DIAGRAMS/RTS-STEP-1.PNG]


1. Insert the large ribbon from the screen into the connector on the bottom of the display driver board and compress the retainer clip.
2. Insert the small ribbon from the screen into the connector on the top of the display driver board and compress the retainer clip.
3. Attach the display driver board to the screen using the supplied risers.

### Step 2
Assemble the frame.

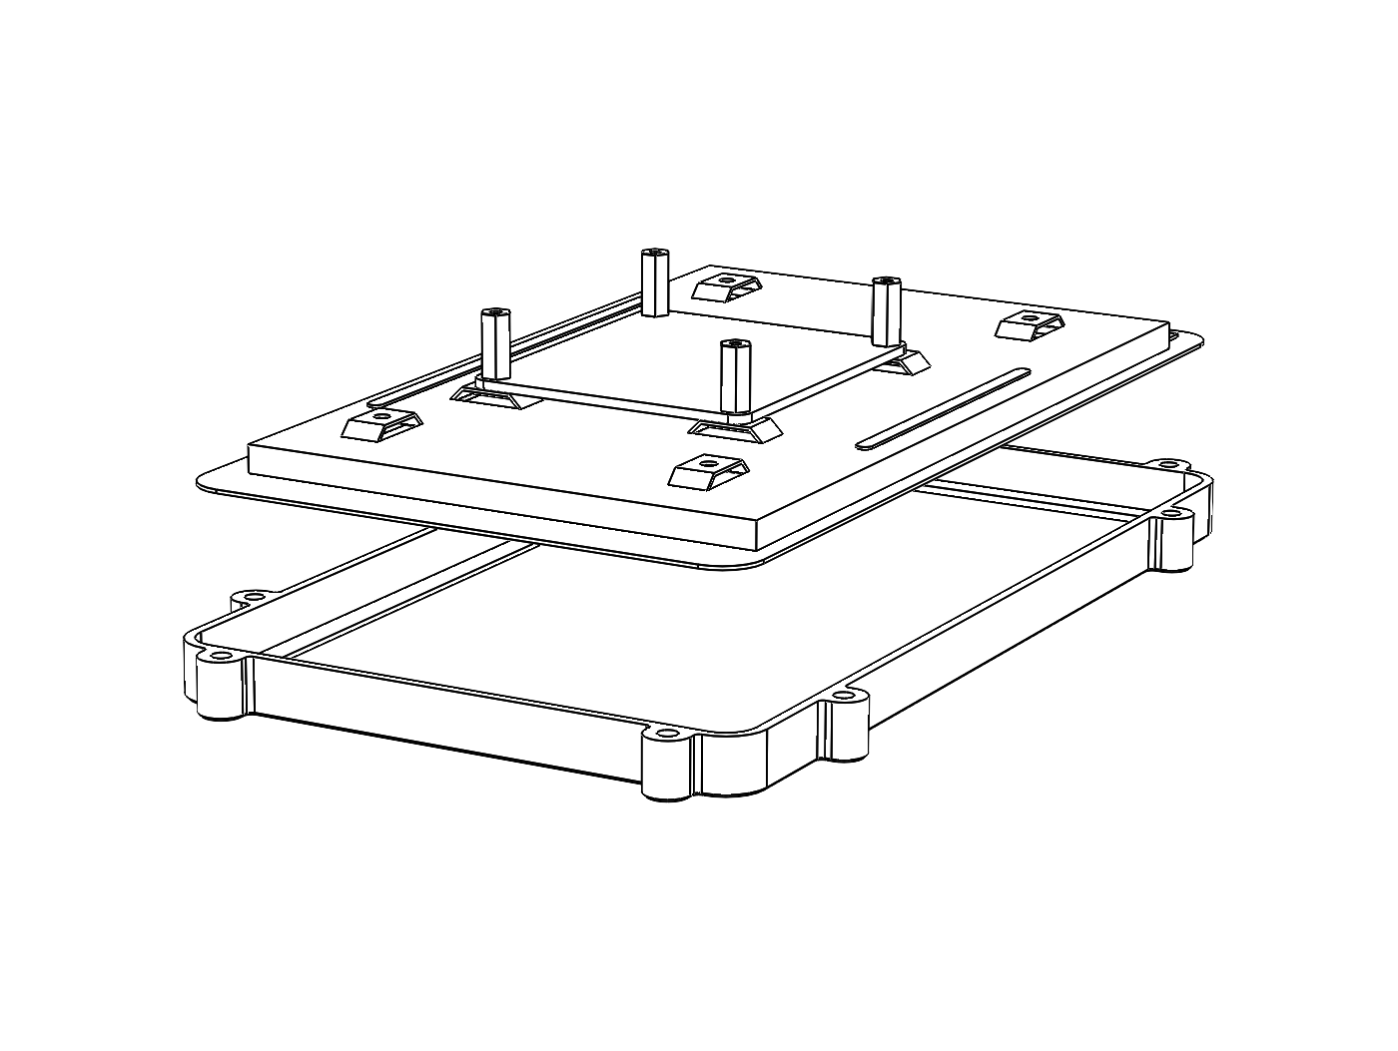
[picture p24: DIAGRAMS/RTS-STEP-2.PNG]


1. Simply insert the screen into the RTS-FRAME through the back.
2. Insert the supplied display ribbon into the connector on the side of the display driver board and secure with the clip.
3. Insert the supplied red wire on pin 1 of the header on the display driver board.
4. Insert the supplied black wire on pin 4 of the header on the display driver board.

### Step 3
Attach the frame to the back.

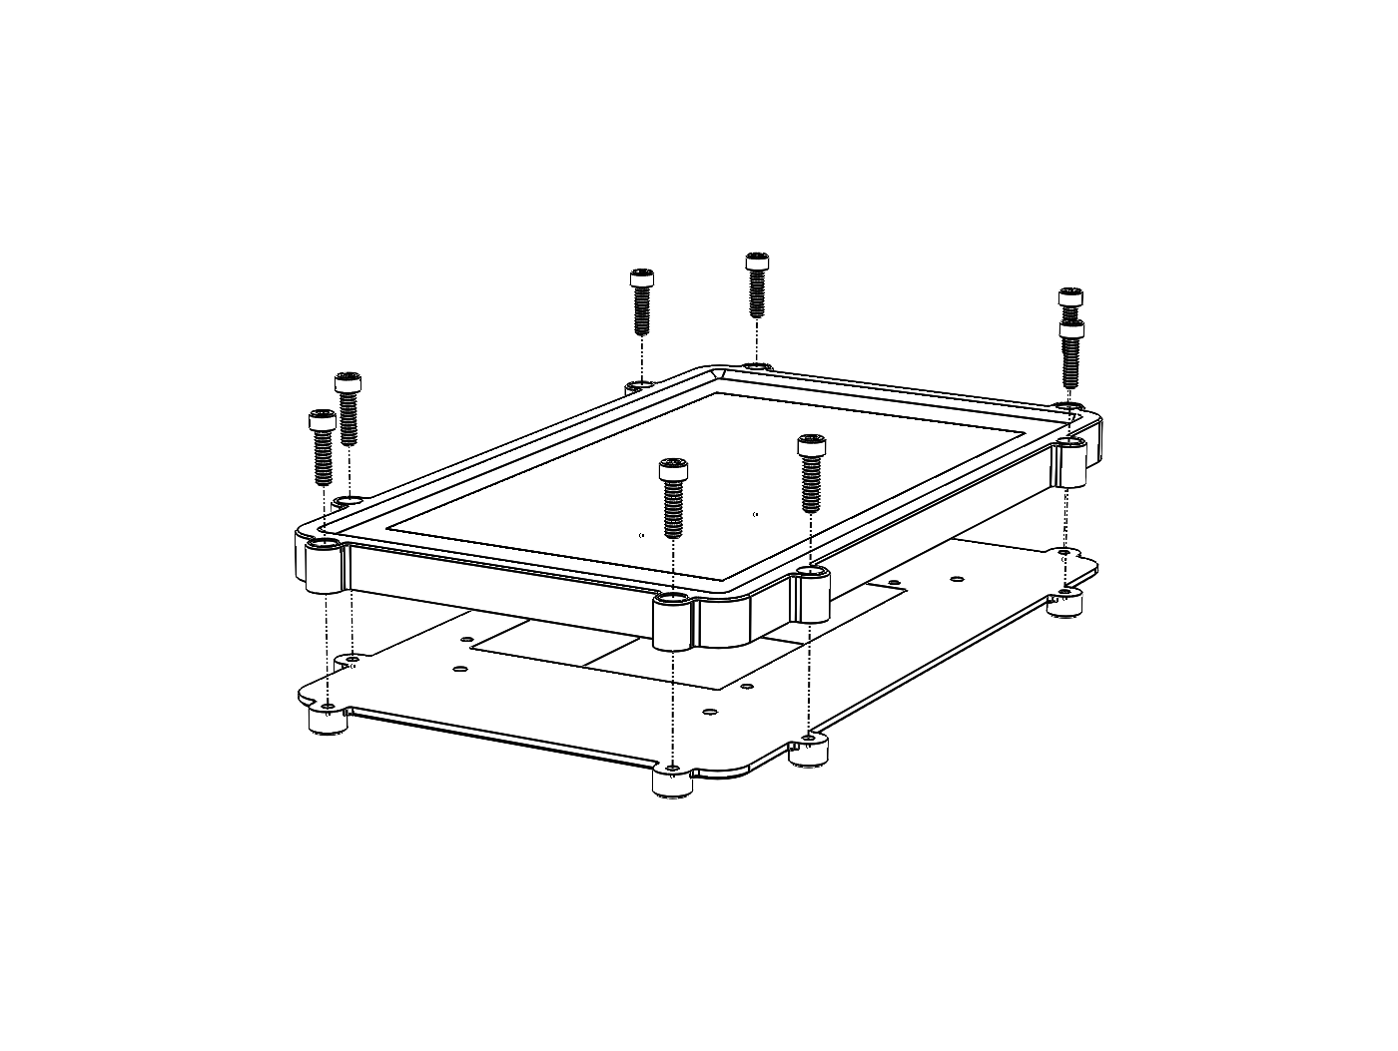
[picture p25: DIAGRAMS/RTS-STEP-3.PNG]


1. Thread the display ribbon, red wire and black wire through the opening in the RTS-BACK.
2. Place the frame assembly onto the RTS-BACK.
3. Secure the frame using the 8 #6-32 x 1/2 stainless socket head cap screws.

### Step 4
Attach the Raspberry Pi 3 B+ to the screen.

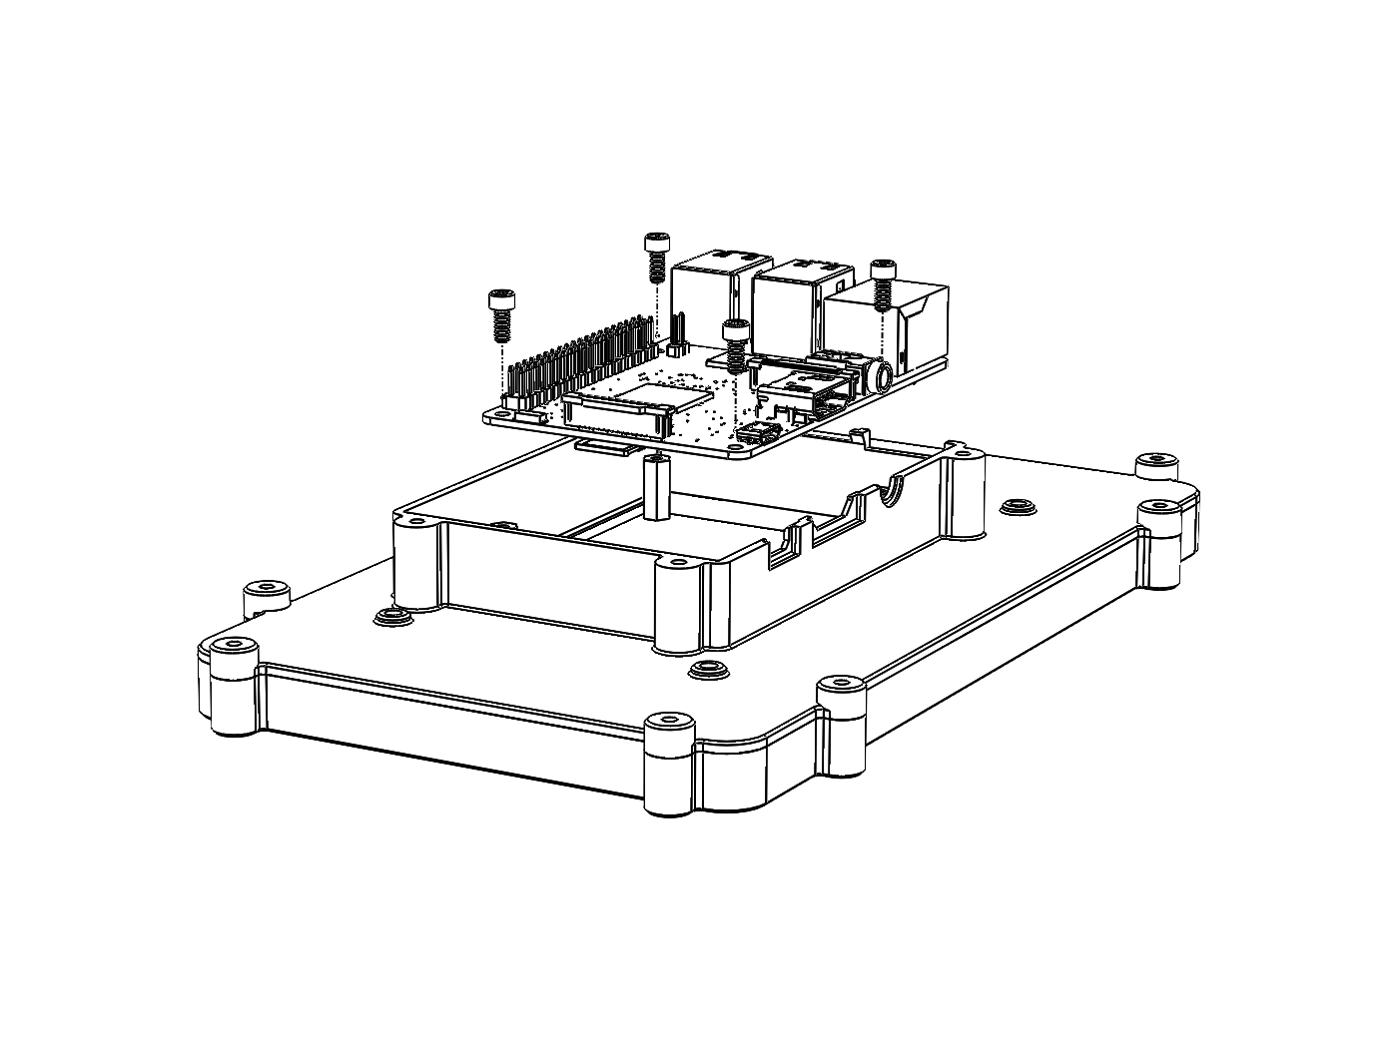
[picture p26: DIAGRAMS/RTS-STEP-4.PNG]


1. First attach the display ribbon into the display connector on the Raspberry Pi and secure with the clip.
2. Insert the red wire on pin 1 of the header on the Raspberry Pi.
3. Insert the black wire on pin 3 of the header on the Raspberry Pi.
4. Place the Raspberry Pi on the raisers from step 1, while doing this allign the tabs on the USB ports to the USB openings on the RTS-BACK.
5. Secure the Raspberry Pi to the screen using the supplied screws with the touchscreen.

### Step 5
Attach the RTS-COVER.

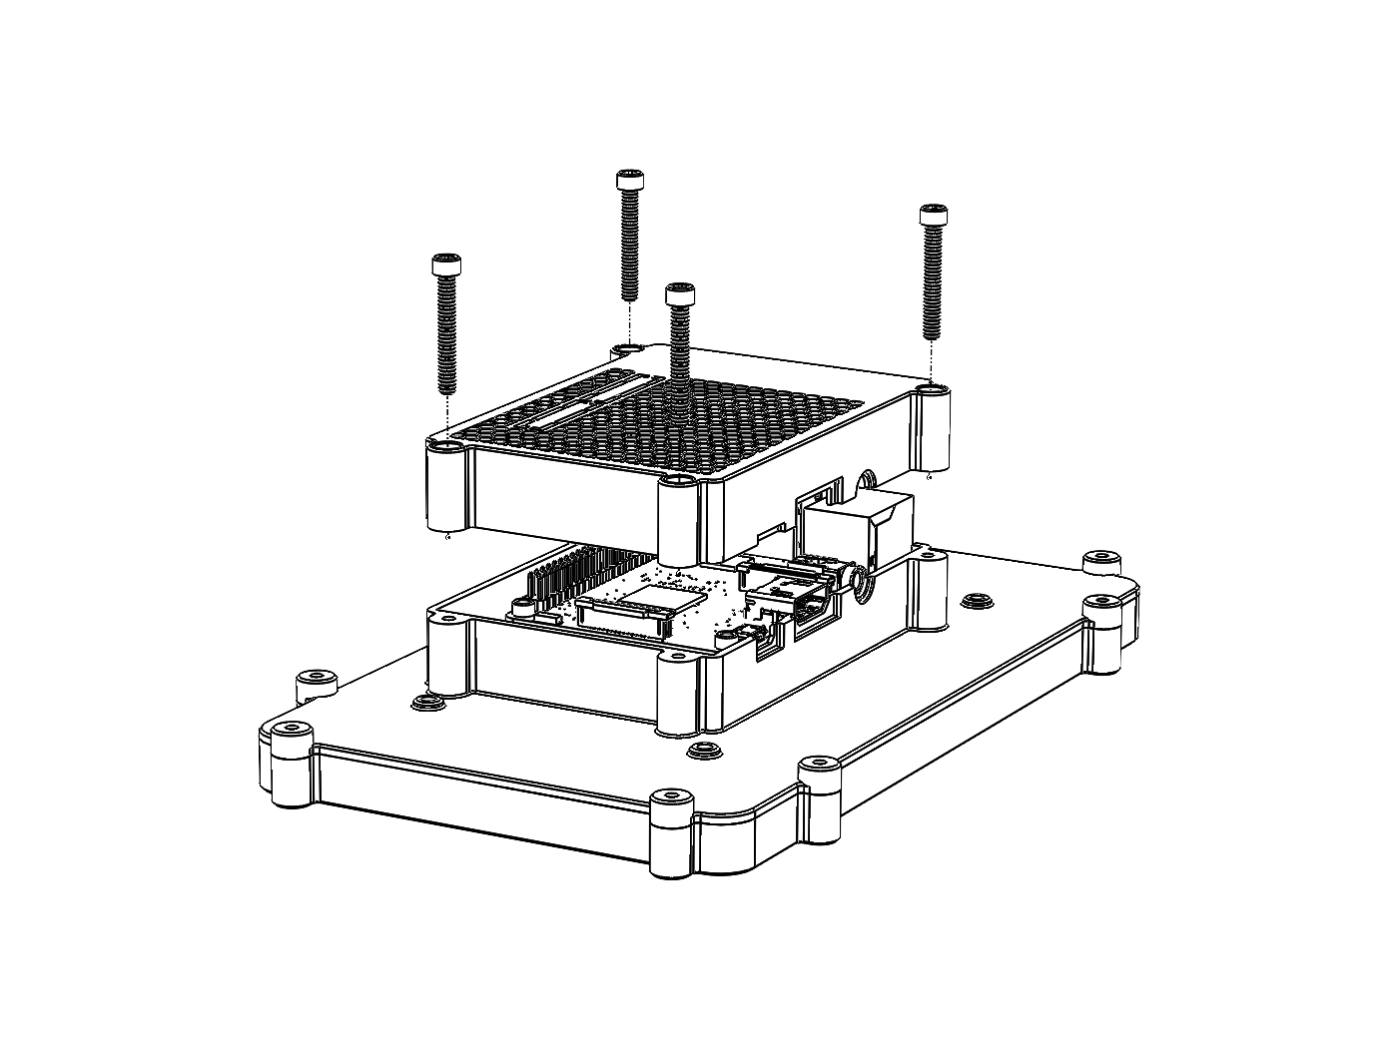
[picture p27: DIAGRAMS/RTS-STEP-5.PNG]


1. Place the RTS-COVER onto the RTS-BACK.
2. Secure the cover with 4 #6-32 x 1 stainless socket head cap screws.

### Step 6
Attach the legs.

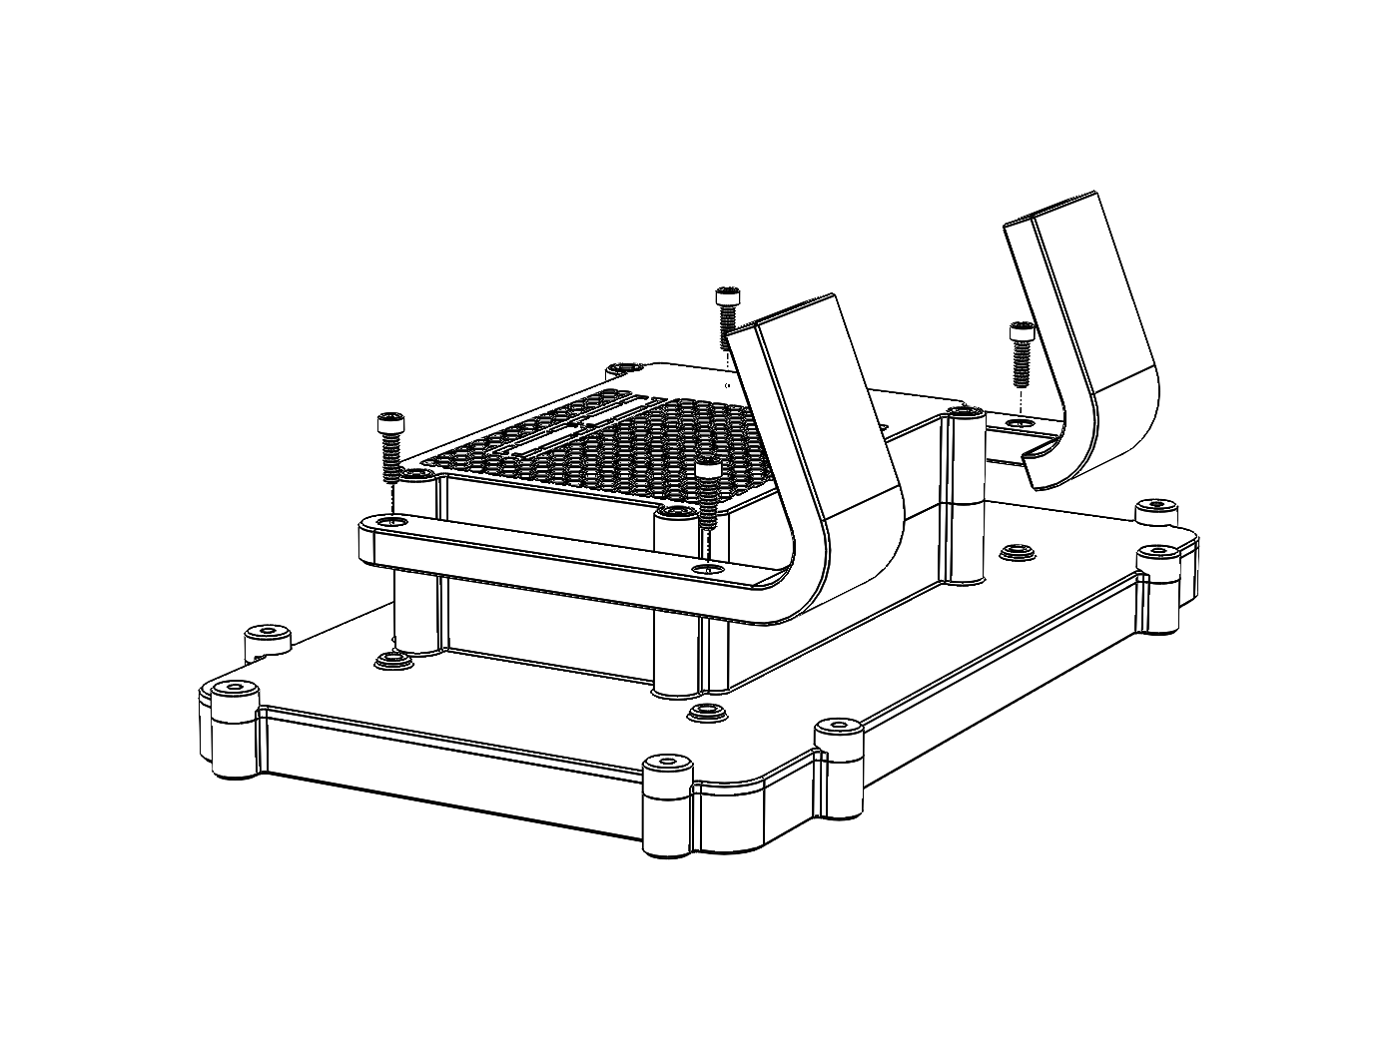
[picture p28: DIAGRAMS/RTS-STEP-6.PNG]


1. Place the corrisponding leg onto the RTS-BACK. There is a right and left leg. The wider part goes in twards the center.
2. Ensure that that the USP mini power plug faces down twards the base of the legs.
3. Secure using 4 #4-40 x 3/8 stainless socket head cap screws.

  > The tap on the screen is a M3 metric thread. The #4-40 screws will work but might alter the threads. #4-40 screws were chosen because they are easier to find. Also 3/8 inch screws are the max length you should use here. If the screws are longer they can damage the back of the screen.

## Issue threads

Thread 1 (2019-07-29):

Any plans to upgrade the project for the new rpi4B?

repcsi, 2019-07-29:
Do you have any plans to upgrade the project for the new rpi4B? I desperately need a hackable case that I can use to install a pwm controllable fan, because the new rpi4B 4GB is running 10celsius hotter than the older rpi3B...

mkellsy, 2019-07-30:
I have plans to update this. I need to get a 4B first for measurements. I'll hit up Micro Center this weekend and pick up a couple.

repcsi, 2019-07-30:
Good to hear! Do you have any channels to receive support? I would like to support this effort!

mkellsy, 2019-07-30:
I have tried to set up sponsoring, but they require me to have 100+ stars on the repository.

Good news is the 3 and the 4 are not much different, so it shouldn't take me long.

mkellsy, 2019-07-30:
Just ordered a pi 4. Will be here on Thursday.

repcsi, 2019-07-30:
Cool, just keep in mind that the 4 runs way hotter than the 3 :)
Paypal on your mail? :)

mkellsy, 2019-07-30:
Yep mkellsy@gmail.com

mkellsy, 2019-07-31:
Thank You!

mkellsy, 2019-08-02:
I got the bases done! I will tackle the tops tomorrow.

mkellsy, 2019-08-06:
Update: I did the initial print of the RPI4 case. There are some fitment issues, but overall it is pretty good.

NEXT STEP
- Adjust the fitment with the IO, the RPI4 is 0.5 - 1mm longer then the RPI3
- Adjust the USB-C slot - Top needs to be longer
- The board retainers need to be 0.5 - 1mm longer - board is a bit loose

repcsi, 2019-08-06:
Nice, I could open the case file in fusion360 so this will be perfect!!! :)
How would you install a fan to the top, what would be the best solution?

mkellsy, 2019-08-06:
The pi 4b case is  done. You can download the files here or from Thingverse. https://www.thingiverse.com/thing:3793664

mkellsy, 2019-08-07:
Sorry this project was built with SolidWorks. Not compatible with Fusion 360.

There are tops with bolt patterns for 25, 30 and 40 mm fans. Just secure the fan with screws and run the wire inside the case and connect to the gpio pins.

repcsi, 2019-08-07:
It was not a question, it was a statement :). I managed to open it in fusion360, it can convert solidworks projects. Thank you Michael! :)

Closed 2019-08-06.

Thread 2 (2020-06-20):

please add metric system [enhancement]

kasuke5, 2020-06-20:
The imperial system has no sense at all and should be banned of every territory.

Sorry, I'm just mad about this  (dumb) system, can you please just add metric system to all the mesure ?

mkellsy, 2021-04-21:
It is. The whole design is metric.
I just list the imperial threads for the screws because they are available at Home Depot. M3 screws work too, just not available in US hardware stores.

Closed 2021-04-21.

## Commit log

2019-01-20 Changed the bolt pattern to accommodate #6-32 screws.
    [RPI-BOTTOM-100VESA.SLDPRT, RPI-BOTTOM-100VESA.STL, RPI-BOTTOM-75VESA.SLDPRT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]
2019-01-20 Added more screen frame mounts
    [DRIVER-BOARD.SLDPRT, FRAME.SLDPRT, FRONT-GLASS.SLDPRT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]
2019-01-21 Updated renderings and added diagrams for RTS
    [RTS-CASE.SLDASM, RTS.SLDASM]
2019-01-21 Added assembly instructions for RTS
2019-01-22 Added RPI blank configurations
    [RPI-TOP-25FAN-BLANK.SLDPRT, RPI-TOP-25FAN-BLANK.STL, RPI-TOP-30FAN-BLANK.SLDPRT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]
2019-01-22 Added RTS blank configurations
    [RTS-COVER-25FAN-BLANK.SLDPRT, RTS-COVER-25FAN-BLANK.STL, RTS-COVER-30FAN-BLANK.SLDPRT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]
2019-01-22 Added RPI assembly instructions
2019-01-23 Removed useless exploded view from RTS
    [RTS.SLDASM]
2019-01-23 Added the 2U rack mount case
    [2U-BLANK.SLDPRT, RTS.SLDASM, T2U-CASE.SLDASM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]
2019-08-06 restructure and add rpi 4b models
    [2.54 mm DUPONT MALE PIN HEADER, IO, 2X20, RPi4ModelB.SLDPRT, 2.54 mm DUPONT MALE PIN HEADER, IO, 2X40, RPi4ModelB.SLDPRT, 2.54 mm DUPONT MALE PIN HEADER, POE, 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]
2019-08-11 components and full cover design
    [6-32_75_CAP.SLDPRT, FAN_25MM.SLDPRT, FAN_30MM.SLDPRT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]
2019-08-11 added full and slim versions
    [4-40_CAP_SCREW.SLDPRT, 6-32_75_CAP.SLDPRT, 6-32_CAP_SCREW.SLDPRT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]
2019-08-11 added full and slim stl files
    [BOTTOM-8020.STL, BOTTOM-8020_BLANK.STL, BOTTOM.STL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]
2019-08-11 stl file orientation
    [TOP.STL, TOP_25MM.STL, TOP_25MM_BLANK.STL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]
2019-08-16 added fan grills
    [GRILL_25MM.SLDPRT, GRILL_25MM.STL, GRILL_30MM.SLDPRT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]
2020-09-30 better renderings
    [2.54 mm DUPONT MALE PIN HEADER, IO, 2X20, RPi4ModelB.SLDPRT, 2.54 mm DUPONT MALE PIN HEADER, POE, 2X2, RPi4ModelB.SLDPRT, 25MM-FAN.SLDPRT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]
2020-09-30 added pi 4 touchscreen case
    [BACK.SLDPRT, BACK.STL, BEZEL.SLDPRT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]
2020-09-30 added 40 mm fan cover
    [RTS-COVER-40FAN-BLANK.SLDPRT, RTS-COVER-40FAN-BLANK.STL, RTS-COVER-40FAN.SLDPRT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]
2020-10-01 added wind tunnel case
    [2X USB2.0 PORTS, RPi4ModelB.SLDPRT, 2X USB3.0 PORTS, RPi4ModelB.SLDPRT, BAFFLE.SLDPRT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]
2020-10-23 added screen clearance for touchscreen cases
    [BACK.SLDPRT, BACK.STL, BEZEL.SLDPRT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]
